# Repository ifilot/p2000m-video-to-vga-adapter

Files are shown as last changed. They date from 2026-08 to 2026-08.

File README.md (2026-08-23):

# Philips P2000M video to VGA adapter



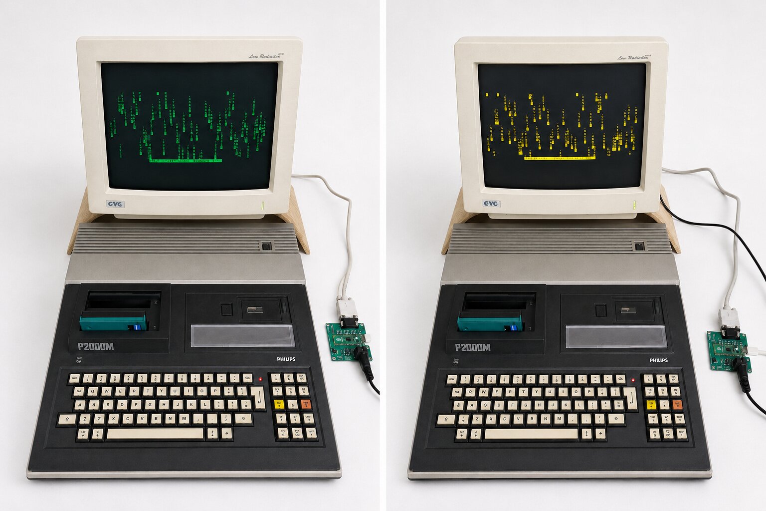
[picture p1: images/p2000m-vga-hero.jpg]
Philips P2000M connected to a monitor through the VID2VGA adapter


This repository contains the adapter PCB and Raspberry Pi Pico 2 firmware for
converting the Philips P2000M raw monochrome video output to VGA.

The adapter captures the conditioned P2000M signals on GPIO16-18,
recovers the source dot grid in software, and presents a tear-free 640 x 288
source image in a 640 x 480, 60 Hz VGA raster. The asynchronous 50.095 Hz
source is repeated as needed at VGA frame boundaries.

By default, the 288 source lines are displayed one-to-one between 96-line top
and bottom margins. An optional fit mode expands them to all 480 VGA lines using
symmetric nearest-neighbour 5:3 scaling. Each three-line source group becomes
five output lines in a 2,1,2 repetition pattern, preserving hard text edges
without introducing gray interpolation pixels.

## Hardware

The adapter conditions the P2000M video and synchronization signals for the
Pico 2, then converts the Pico's 12-bit RGB output and synchronization signals
to a standard VGA connection.

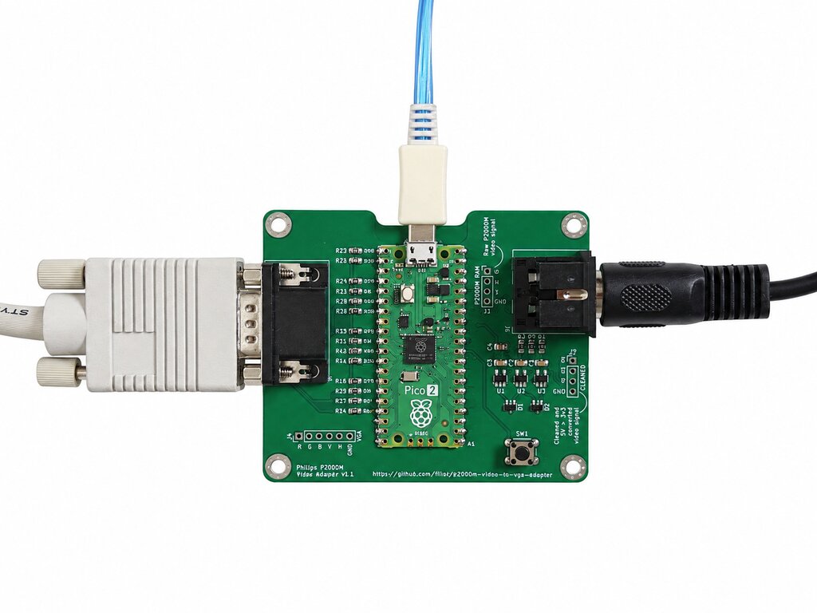
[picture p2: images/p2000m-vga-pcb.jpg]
Assembled P2000M VID2VGA adapter PCB with connected cables


*Assembled adapter PCB. The board design is in
[`pcb/p2000m-to-vga-adapter.kicad_pcb`](pcb/p2000m-to-vga-adapter.kicad_pcb).*

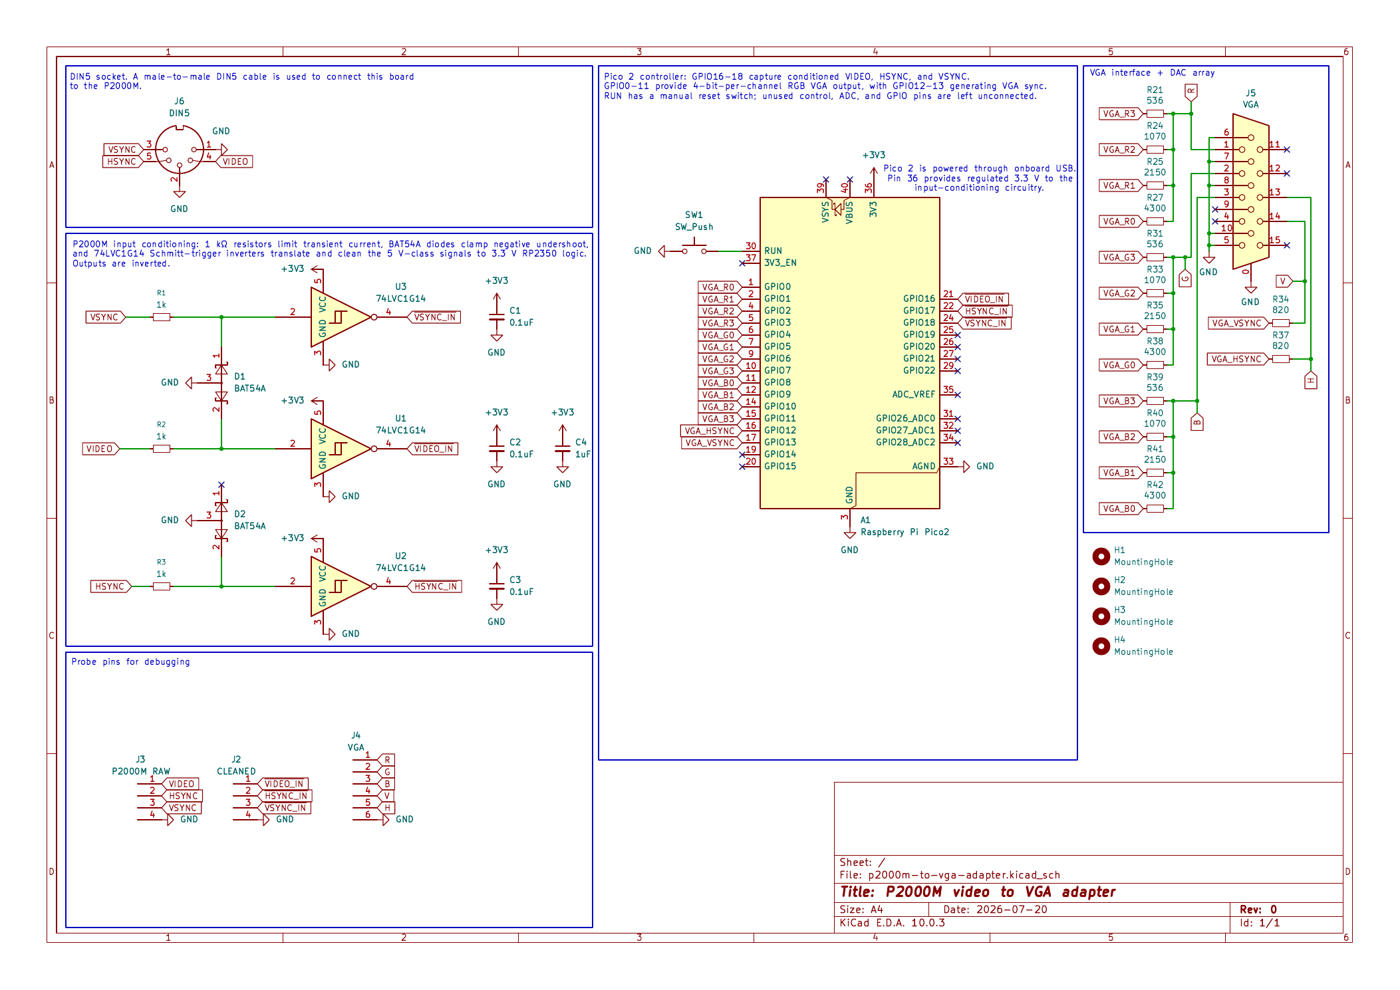
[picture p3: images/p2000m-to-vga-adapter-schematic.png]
Circuit schematic for the P2000M VID2VGA adapter


*Circuit schematic. Select the image to open the PDF; the editable source is
[`pcb/p2000m-to-vga-adapter.kicad_sch`](pcb/p2000m-to-vga-adapter.kicad_sch).*

### Enclosure

A two-part 3D-printable enclosure protects the assembled adapter while keeping
its connectors, USB port, and controls accessible. Ready-to-print models are
available as [`enclosure/v1/top.stl`](enclosure/v1/top.stl) and
[`enclosure/v1/bottom.stl`](enclosure/v1/bottom.stl).

<p align="center">
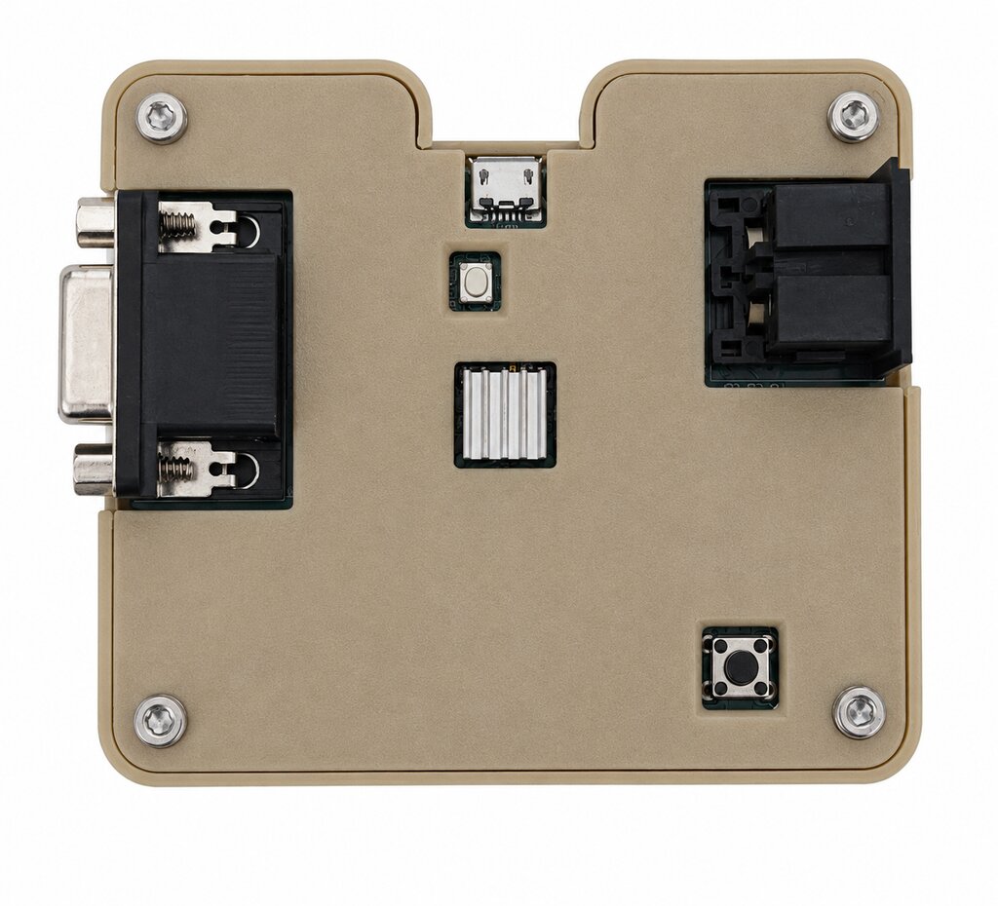
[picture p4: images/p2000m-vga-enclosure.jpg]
P2000M VID2VGA adapter fitted in its enclosure
  
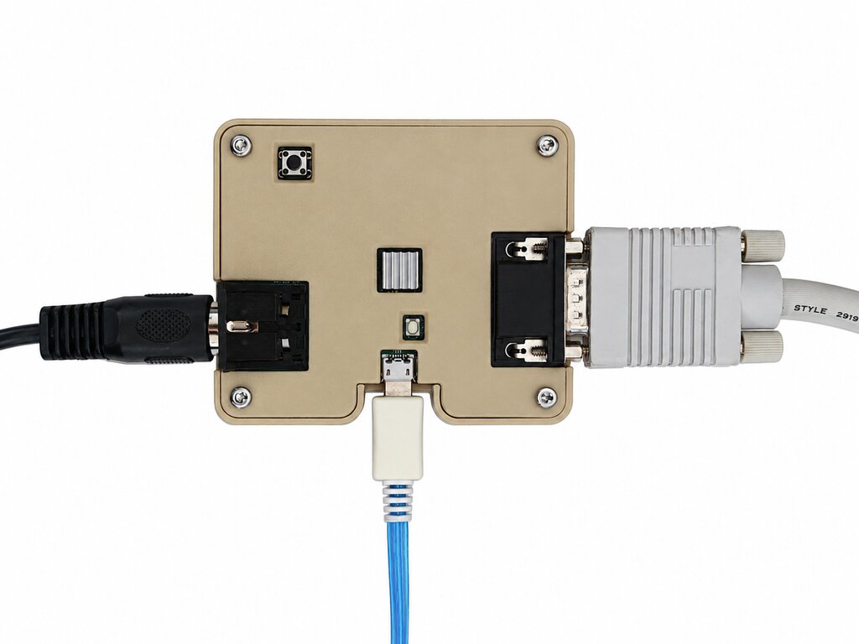
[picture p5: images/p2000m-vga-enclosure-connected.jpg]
Enclosed P2000M VID2VGA adapter with cables connected
  
</p>

## Building

The build requires Git, CMake, Ninja, and an Arm GNU embedded toolchain. The
first configuration automatically downloads the pinned Pico SDK 2.3.0 and
matching `pico-extras` release into the build directory; later configurations
reuse those checkouts.

On Debian or Ubuntu, install the host tools and cross-compiler with:

```sh
sudo apt update
sudo apt install git cmake ninja-build build-essential \
  gcc-arm-none-eabi libnewlib-arm-none-eabi \
  libstdc++-arm-none-eabi-newlib
```

```sh
cmake -S . -B build -G Ninja \
  -DCMAKE_BUILD_TYPE=Release
cmake --build build
```

Pico 2 and its `rp2350-arm-s` platform are project defaults, so
`-DPICO_BOARD=pico2` is no longer necessary.

For an offline or custom SDK installation, explicitly pass
`-DPICO_SDK_PATH=/path/to/pico-sdk` and
`-DPICO_EXTRAS_PATH=/path/to/pico-extras`; these overrides take precedence over
automatic downloading.

Flash the single generated image:

```text
build/src/p2000m-vid2vga-firmware.uf2
```

> [!WARNING]
> The current experimental firmware runs the RP2350 at 252 MHz and 1.30 V,
> beyond Raspberry Pi's 150 MHz rating. This preserves exact integer divisors
> for the 63 MHz capture and 25.2 MHz VGA clocks, but stability, temperature,
> lifetime, and operation across devices are not guaranteed. BOOTSEL recovery
> remains available if the firmware does not start reliably. The configuration
> that sustained 25 FPS was tested with a cooling block fitted directly to the
> RP2350 package. A properly mounted heatsink or equivalent cooling block, with
> adequate surrounding airflow, is strongly recommended for prolonged use at
> 252 MHz; cooling reduces thermal risk but does not make the overclock an
> in-spec operating condition.

### Desktop screen viewer

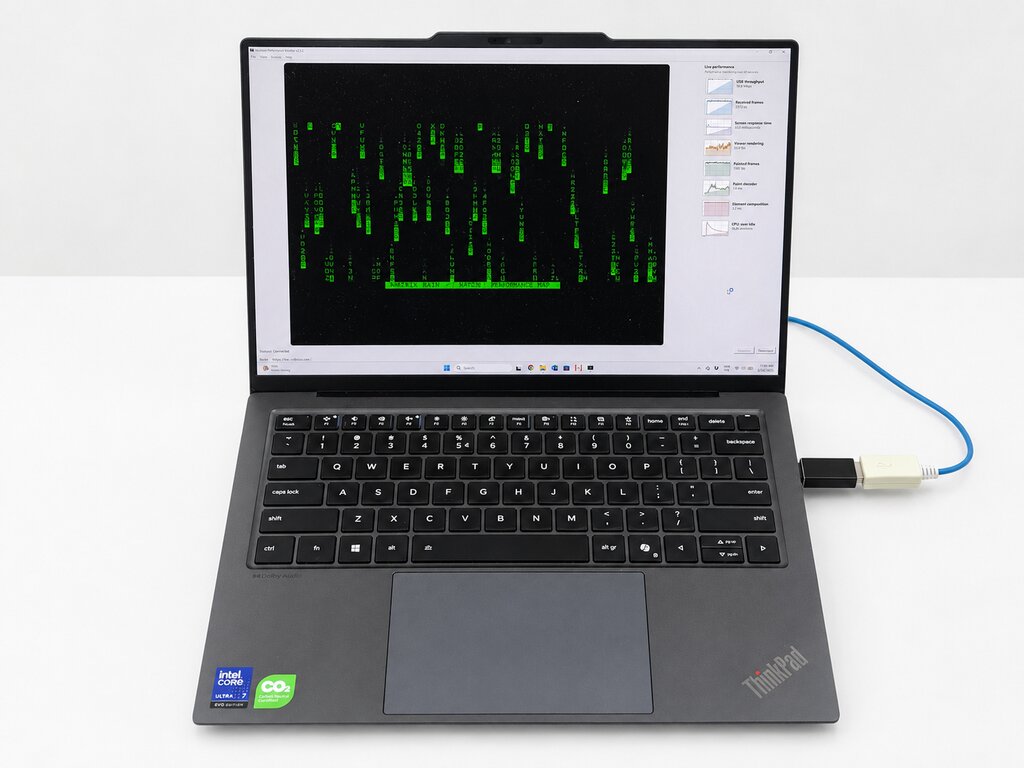
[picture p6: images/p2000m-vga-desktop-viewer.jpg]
P2000M desktop screen viewer running on a laptop


The `gui` directory contains a Qt 6 application for Windows, Linux, and macOS.
It automatically finds Raspberry Pi Pico CDC ports, verifies the VID2VGA
firmware, switches the adapter into binary screen mode, and displays complete
CRC-checked frames. It
returns the adapter to console mode when Disconnect is selected or the window
is closed. Its Adapter menu can configure colors, borders, scaling, phosphor
grain, sampling phase, and optional persistent storage through the firmware's
console.
The viewer uses a monitor-derived application icon, places rolling live
performance graphs beside the screen, and keeps the status bar focused on the
COM port and source frame number. It can save lossless screenshots and can
record H.264 MP4 video through the FFmpeg runtime included in every packaged
viewer distribution.

Build it from an MSYS2 UCRT64 shell with Qt 6 installed:

```sh
cmake -S gui -B build-gui -G Ninja -DCMAKE_BUILD_TYPE=Release
cmake --build build-gui
```

See [`gui/README.md`](gui/README.md) for use and build instructions and
[`gui/PACKAGING.md`](gui/PACKAGING.md) for CI packaging and tagged releases.

## Video capture and VGA conversion

The P2000M connector does not carry a VGA-compatible raster. It exposes a
one-bit monochrome `VIDEO` signal plus separate `HSYNC` and `VSYNC` timing
signals. The adapter first converts those signals to safe 3.3 V logic, then the
Pico measures and reconstructs the original dot grid before generating a new,
independent VGA raster. The complete path is:

```text
P2000M DIN-5 -> protection and Schmitt-trigger conditioning
             -> PIO sampling and DMA raw-frame buffers
             -> 640 x 288 one-bit reconstructed frames
             -> color mapping and 640 x 480 VGA scanout
```

### P2000M source timing

The P2000M derives its display timing from a 12 MHz dot clock. Eight dots form
one character time and 96 character times form one 64 microsecond scanline.
Only 80 character times contain picture data, giving 640 visible dots per line.
Twelve scanlines form a character row and 26 hardware rows form a frame, for a
nominal frame rate of approximately 50.1 Hz.

The 24 rows stored in video memory do not have the same numbers as the hardware
timing rows. Video-memory rows 0 through 23 appear in hardware rows 1 through
24. Hardware rows 25 and 0 are part of the vertical blanking and preparation
interval. `VSYNC` is active during hardware row 24, the final visible row:

```text
hardware row 24  video-memory row 23; VSYNC active
hardware row 25  vertical blanking                     } skipped
hardware row 0   vertical blanking / row preparation   } skipped
hardware row 1   video-memory row 0; capture starts
       ...
hardware row 24  video-memory row 23; capture ends
```

The capture state machine waits for the trailing edge of the active-low
conditioned `VSYNC`, which marks the start of hardware row 25. It then counts 24
`HSYNC` edges to skip hardware rows 25 and 0. Capturing the following 288
scanlines therefore covers hardware rows 1 through 24, or exactly 80 x 24
characters. This distinction is important: treating the assertion of `VSYNC`
as row 0 would capture one blank character row and omit video-memory row 23.

### Probing and input conditioning

The three P2000M signals enter through the DIN-5 connector. Each input has a
1 kΩ series resistor to limit transient current and a BAT54A clamp for negative
undershoot. A 3.3 V-powered 74LVC1G14 Schmitt-trigger inverter translates the
5 V-class input to RP2350 logic levels, cleans up slow or noisy edges, and
inverts its polarity before it reaches the Pico:

| P2000M signal | Conditioned signal | Pico input | Purpose |
| --- | --- | --- | --- |
| `VIDEO` | `~VIDEO_IN` | GPIO16 | Monochrome dot level |
| `HSYNC` | `~HSYNC_IN` | GPIO17 | Start reference for every scanline |
| `VSYNC` | `~VSYNC_IN` | GPIO18 | Frame and hardware-row reference |

All three conditioned inputs are consequently active-low. For `VIDEO`, a low
sample represents foreground and a high sample represents background.

### Line capture and pixel reconstruction

PIO1 runs at 63 MHz and anchors every captured line independently to the
leading edge of conditioned `HSYNC`. After a fixed delay to just before the
active picture, it oversamples `VIDEO` for 54.286 microseconds. Independent
line synchronization prevents small timing errors from accumulating vertically.

The PIO loop takes 14 consecutive samples followed by one branch cycle without
a sample. Two loops are packed into each DMA word, so a word holds 28 useful
samples representing 30 PIO clock ticks. A line contains 114 words and a raw
frame contains 288 such lines. DMA writes complete frames into three buffers so
capture can continue while software reads an older completed frame.

The source clock is not phase-locked to the Pico. The firmware therefore
measures the source frame period, divides it over the known 312 scanlines and
768 dot periods per line, and builds a map from each of the 640 output pixels to
the appropriate raw samples. It tests five nearby horizontal phases and selects
the phase with the strongest foreground content. For each reconstructed pixel,
three adjacent samples are examined; if any is foreground, the output pixel is
foreground. This preserves narrow character strokes without introducing gray
interpolation pixels. A double-buffered map ensures that a timing adjustment
cannot change partway through decoding a frame.

Core 0 converts the newest completed raw capture into a packed 640 x 288 one-bit
frame. Three decoded-frame buffers separate this work from VGA generation on
core 1.

### VGA presentation

The Pico generates a standard 640 x 480 raster with a 25.2 MHz pixel clock and
a nominal 60 Hz refresh rate. The P2000M and VGA rates are asynchronous, so core
1 switches to the newest decoded source frame only at the beginning of a VGA
frame. If no newer P2000M frame is ready, it repeats the current one. A VGA
frame can therefore never contain parts of two source frames.

Complete captured frames also act as a synchronization watchdog. If valid
HSYNC/VSYNC-driven frames stop arriving for 100 ms, VGA remains active and
shows a centered `SIGNAL LOST` warning instead of indefinitely freezing the
last source image. The status card also identifies the adapter and its compiled
firmware version and indicates that capture is waiting for both synchronization
inputs. Live video returns only after two consecutive frame completions
establish a credible source period, preventing a partial recovery frame from
reaching the display.

Horizontally, all 640 reconstructed source pixels map directly to the 640 VGA
pixels. Vertically, native mode presents all 288 source lines one-to-one between
96-line top and bottom margins. Fit mode expands them to 480 lines with
symmetric nearest-neighbour 5:3 scaling: each three-line source group becomes a
2,1,2 pattern of repeated VGA lines.

The one-bit image selects the configured foreground or background color. The
optional border is added during scanout, so it can use an independent color and
a solid or dotted pattern without expanding the one-bit frame buffers. Optional
phosphor grain uses a source-frame-synchronous pseudorandom mask to dim only
foreground pixels by one RGB444 DAC step. Low, medium, and high select roughly
one eighth, one quarter, or one half of the lit pixels; background, borders,
and the captured framebuffer remain unchanged. GPIO0 through GPIO11 carry four
bits each of red, green, and blue through the resistor DAC, while GPIO12 and
GPIO13 generate VGA synchronization. After every 640-pixel picture line, the
scanout emits black before horizontal blanking so the analog RGB outputs return
to a defined level before synchronization.

## USB controls

Connect a terminal to the Pico USB CDC serial port. Commands are
case-insensitive and execute when Enter is pressed. Command mode echoes input,
supports Backspace/Delete, displays a `vid2vga>` prompt, and produces no
unsolicited statistics.

- `status` or `s`: print capture, decoder, resampler, and VGA statistics.
- `version` or `v`: print the semantic firmware version.
- `license`: print the firmware copyright, license, warranty, and source
  location.
- `log`: stream those statistics every two seconds. Press Enter, Escape, or
  `q` to stop the stream and return to the command prompt.
- `screen [raw|packbits]`: enter the continuous binary framebuffer interface
  used by the Windows viewer. TinyUSB backpressure safely pauses transmission
  when the host cannot keep up, `console` returns to the normal terminal
  interface, and the legacy `frame` command remains accepted for viewer
  compatibility. Omitting the encoding selects raw records.
- `settings`: print all active settings and whether they are factory defaults,
  modified in RAM, or saved in flash.
- `border on`, `border off`, or `border toggle`: control a one-pixel rectangle
  around the 640 x 288 source image.
- `border-color <color>`: set the border color independently of the foreground
  and background colors.
- `border-style solid` or `border-style dotted`: select a continuous border or
  a two-pixel-on, two-pixel-off pattern whose gaps reveal the source image.
- `scale fit`: expand 288 source lines to the full 480-line VGA height.
- `scale native`: show the original 288 lines between 96-line margins.
- `noise off`, `noise low`, `noise medium`, or `noise high`: select the density
  of one-DAC-step phosphor grain applied to foreground pixels.
- `fg <color>`: set the foreground/text color.
- `bg <color>`: set the background color, including the top and bottom margins.
- `colors`: list the named presets.
- `defaults`: restore white on black, a disabled solid magenta (`#FF00FF`)
  border, native 1:1 scaling, and disabled phosphor grain.
- `save`: explicitly save the current colors, border state, border pattern,
  scaling mode, phosphor-grain level, and manual phase trim. These settings are
  restored after reset or power cycling.
- `factory-reset`: erase the saved configuration and immediately restore the
  factory display style and zero manual phase trim.
- `tune` or `j`: run automatic phase tuning and print all candidate scores.
- `phase +`, `phase -`, or `phase auto`: adjust or clear the manual phase trim.
- `geometry` or `g`: print coverage totals for all 80 x 24 character cells.
- `help`, `h`, or `?`: print the command reference.

Colors may be selected by name (`black`, `white`, `green`, `amber`, `cyan`,
`magenta`, `red`, `blue`, `yellow`, or `gray`) or entered as `RRGGBB`,
`#RRGGBB`, or `0xRRGGBB`. The VGA output hardware is RGB444, so the upper four
bits of each entered eight-bit channel determine the physical output level.

Settings are only written when `save` is entered, avoiding unnecessary flash
wear while experimenting. Two versioned, checksummed flash records are used in
alternation, so an interrupted save leaves the previous valid configuration
available. Saving or erasing briefly pauses both cores and may cause a momentary
VGA blink. Automatic phase selection is always recalculated from the live
signal; only the user's manual phase trim is persistent.

Automatic tuning runs about once every five seconds. The `stale_replaced`
counter normally increases when newer raw frames supersede frames that no
consumer needed; it is not itself a capture failure.

Screen mode sends a 48-byte versioned header followed by a complete packed
monochrome framebuffer. Type-one records contain the native 23,040-byte image.
Type-two records use standard PackBits controls: 0 through 127 introduce 1
through 128 literal bytes, 129 through 255 repeat the next byte 128 through 2
times, and 128 is a no-op. PackBits is selected independently for each frame
only when smaller than raw data, so incompressible screens cannot expand the
USB traffic. PackBits runs are aggregated into approximately 1 KiB staging
blocks before entering TinyUSB. The payload-size header field describes the
transmitted data and its CRC-32 always covers the reconstructed 23,040-byte
framebuffer. When flags bit 2 is set, header bytes 12 through 15 contain two
little-endian 16-bit diagnostics: current preparation time and previous-frame
streaming-encoder CPU time, both in microseconds.
Header style bits 3 and 4 carry the phosphor-grain level; the packed payload and
its checksum continue to describe the pristine one-bit source framebuffer.

Frames are independently recoverable and limited to every second decoded
source sequence (approximately 25.05 frames per second).
USB transmission is continuous and best effort: a slow or disconnected host
can reduce the viewer rate but cannot take the framebuffer currently required
by VGA output. The current viewer selects raw records by default and offers
PackBits as an experimental Adapter-menu option. It also negotiates the older
per-frame credit mode when connected to an earlier compatible firmware build.
Plain `screen` remains raw for older viewer compatibility.

## Licensing

This is a multi-license project:

- The firmware, build configuration, CI workflow, and P2000M screen-test
  program are licensed under the
  [GNU GPL version 3 or later](LICENSES/GPL-3.0-or-later.txt).
- The PCB, schematic, custom footprints, and generated hardware views are
  licensed under the
  [CERN Open Hardware Licence Version 2—Strongly Reciprocal](LICENSES/CERN-OHL-S-2.0.txt).
- This README and the changelog are licensed under
  [Creative Commons Attribution 4.0](LICENSES/CC-BY-4.0.txt).

See [LICENSE.md](LICENSE.md) for the exact file scopes and
[THIRD_PARTY_NOTICES.md](THIRD_PARTY_NOTICES.md) for components incorporated
from the Raspberry Pi Pico SDK, `pico-extras`, and TinyUSB.

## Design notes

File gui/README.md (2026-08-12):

<!--
SPDX-FileCopyrightText: 2026 Ivo Filot <ivo@ivofilot.nl>
SPDX-License-Identifier: CC-BY-4.0
-->

# P2000M VID2VGA Viewer

The Qt 6 viewer automatically enumerates Raspberry Pi Pico USB CDC ports on
Windows, Linux, and macOS, verifies the VID2VGA firmware, enters binary screen
mode, and displays complete CRC-checked frames. Disconnecting or closing the
application returns the adapter to its normal console mode. The application
version is visible in the window title, **Help > About**, Qt application metadata, and the Windows
executable properties.

The viewer uses continuous streaming with current firmware to avoid a USB
command round trip between frames. It automatically falls back to per-frame
credits when it recognizes an earlier version-one firmware announcement. Raw
streaming is the default. **Adapter > Stream Encoding** can switch a live
connection to experimental PackBits mode without reconnecting; compressed
records have their expanded CRC-32 validated and fall back to raw whenever
compression is ineffective.

The right-hand **Live performance** panel plots approximately 60 seconds of
rolling history for USB throughput, received and painted frame rates, source
sequence step, payload size, rendering and PackBits times, paint time,
firmware preparation and encoding times, and the rolling CRC-error rate. Raw
mode hides the payload-size, PackBits-unpacking, and firmware-encoding graphs
because those compression metrics do not apply. The status bar is reserved
for operational information: the active COM port, source frame number,
cumulative CRC errors for the current capture, and recording state.

The **Adapter > Configure Adapter** dialog controls foreground, background,
border color and style, vertical scaling, foreground phosphor grain, and
sampling-phase trim. **Apply** changes the running configuration; **Apply &
Save** also stores it in the adapter's redundant flash settings slots. The
viewer briefly pauses screen traffic, uses the firmware's normal USB console
commands, and resumes the binary stream on the same COM port. Grain controls
are disabled when connected to firmware older than v0.4.0. The foreground can
be selected from Matrix green, retro amber, and warm off-white presets or from
the unrestricted custom color picker.

The menu bar also provides connection controls, lossless framebuffer
screenshots, and MP4 recordings under **File**, plus application and license
information under **Help > About**. Both save dialogs offer a remembered option
to add a 12 px black border, producing a 664 x 504 image instead of the native
640 x 480 frame. Recordings are encoded by a separate FFmpeg process, keeping
video compression away from the serial and painting paths. The live monitor
viewport has a permanent 12 px black bezel with rounded outer and screen
corners; this presentation-only surround is not included in captures. If the
adapter remains connected but valid source frames stop for 100 ms, the viewer
shows the same `SIGNAL LOST` card as the VGA output and restores the live image
as soon as capture resumes. **View > Scaling
Filter** switches between smooth anti-aliased resizing and sharp
nearest-neighbor pixels. Pixel-perfect integer scaling avoids uneven pixel
widths. **View > CRT Phosphor Afterglow** optionally retains decaying light
from earlier frames; its brightness half-life is tunable from 10 to 1000 ms
and both settings persist between viewer sessions. The effect is limited to
presentation, so recordings and lossless framebuffer screenshots retain the
unfiltered adapter image. **F11** enters a clean full-screen presentation and
**Escape** leaves it. The monitor-derived application icon is used by the
executable, main window, dialogs, and taskbar.

The application uses SetupAPI and direct COM access on Windows, preserving the
high-throughput path tested with the adapter. Linux and macOS use a compact
native POSIX serial backend. Qt Serial Port is therefore not required on any
platform; the only Qt dependency is Qt 6 Base.

Build from an MSYS2 UCRT64 shell:

```sh
pacman -S --needed mingw-w64-ucrt-x86_64-qt6-base
cmake -S gui -B build-gui -G Ninja -DCMAKE_BUILD_TYPE=Release
cmake --build build-gui
```

Every distributed viewer package includes a private, smoke-tested FFmpeg/x264
runtime for H.264 recording. The viewer selects that copy before considering a
developer installation on `PATH`. Exact corresponding source archives,
license texts, checksums, and configure arguments are included under
`licenses/ffmpeg`; no separate FFmpeg installation is required.

See [PACKAGING.md](PACKAGING.md) for Linux and macOS builds, package formats,
the default-branch package checks, and the exact-commit tag release process.

The following creates a development directory containing the executable and
its Qt runtime DLLs. It is not a distributable package until the pinned FFmpeg
runtime has also been built and bundled as described in [PACKAGING.md](PACKAGING.md):

```sh
mkdir -p build-gui/package
cp build-gui/p2000m-vid2vga-viewer.exe build-gui/package/
windeployqt6 --release --no-translations \
  build-gui/package/p2000m-vid2vga-viewer.exe
```

MSYS2's Qt packages use several shared UCRT64 libraries which
`windeployqt6` does not copy. Add their recursively discovered dependencies
when the package must run without an MSYS2 `PATH`:

```sh
for binary in $(find build-gui/package -type f \
    \( -name '*.exe' -o -name '*.dll' \)); do
  ldd "$binary"
done | awk '$3 ~ /^\/ucrt64\/bin\// { print $3 }' | sort -u | \
  xargs -r -I{} cp "{}" build-gui/package/
```

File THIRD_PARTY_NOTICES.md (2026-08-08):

<!--
SPDX-FileCopyrightText: 2026 Ivo Filot <ivo@ivofilot.nl>
SPDX-FileCopyrightText: 2020 Raspberry Pi (Trading) Ltd.
SPDX-FileCopyrightText: 2018 hathach (tinyusb.org)
SPDX-License-Identifier: CC-BY-4.0 AND BSD-3-Clause AND MIT
-->

# Third-party notices

The firmware build downloads the pinned Raspberry Pi Pico SDK 2.3.0 and the
matching `pico-extras` release. The generated firmware incorporates portions of
those projects and TinyUSB. Those portions retain their original licenses and
copyright notices. The project's GPL license does not replace them.

The exact dependency source is available from:

- <https://github.com/raspberrypi/pico-sdk/tree/2.3.0>
- <https://github.com/raspberrypi/pico-extras/tree/sdk-2.3.0>
- <https://github.com/hathach/tinyusb/tree/86ad6e56c1700e85f1c5678607a762cfe3aa2f47>

Release packages of the optional desktop viewer also contain dynamically
linked Qt 6 runtime libraries and plugins. Those unmodified libraries retain
their Qt Project licensing, including the GNU Lesser General Public License
version 3 where applicable. Viewer packaging copies the license files supplied
with the exact Qt distribution into the package. Qt source releases and the
corresponding license information are available from <https://www.qt.io/>.

Viewer packages include a private FFmpeg 8.1.2 executable built from unmodified
FFmpeg source and statically linked with x264 revision
`b35605ace3ddf7c1a5d67a2eb553f034aef41d55`. The executable is a separate
process connected to the viewer through standard input. FFmpeg is configured
with `--enable-gpl --enable-version3 --enable-libx264`, so the resulting
runtime is distributed under GNU GPL version 3 or later. x264 is distributed
under GNU GPL version 2 or later.

Every viewer package contains the complete, exact FFmpeg and x264 source
archives used for that platform build, their license texts, SHA-256 checksums,
the full configure arguments, and the runtime's own version report under
`licenses/ffmpeg`. The authoritative upstream locations are:

- <https://ffmpeg.org/releases/ffmpeg-8.1.2.tar.xz>
- <https://code.videolan.org/videolan/x264/-/commit/b35605ace3ddf7c1a5d67a2eb553f034aef41d55>

FFmpeg copyright © 2000–2026 the FFmpeg developers. x264 copyright © 2003–2025
the x264 project. No endorsement by either project is implied.

## Raspberry Pi Pico SDK and pico-extras

Copyright 2020 (c) 2020 Raspberry Pi (Trading) Ltd.

Redistribution and use in source and binary forms, with or without
modification, are permitted provided that the following conditions are met:

1. Redistributions of source code must retain the above copyright notice,
   this list of conditions and the following disclaimer.
2. Redistributions in binary form must reproduce the above copyright notice,
   this list of conditions and the following disclaimer in the documentation
   and/or other materials provided with the distribution.
3. Neither the name of the copyright holder nor the names of its contributors
   may be used to endorse or promote products derived from this software
   without specific prior written permission.

THIS SOFTWARE IS PROVIDED BY THE COPYRIGHT HOLDERS AND CONTRIBUTORS "AS IS"
AND ANY EXPRESS OR IMPLIED WARRANTIES, INCLUDING, BUT NOT LIMITED TO, THE
IMPLIED WARRANTIES OF MERCHANTABILITY AND FITNESS FOR A PARTICULAR PURPOSE ARE
DISCLAIMED. IN NO EVENT SHALL THE COPYRIGHT HOLDER OR CONTRIBUTORS BE LIABLE
FOR ANY DIRECT, INDIRECT, INCIDENTAL, SPECIAL, EXEMPLARY, OR CONSEQUENTIAL
DAMAGES (INCLUDING, BUT NOT LIMITED TO, PROCUREMENT OF SUBSTITUTE GOODS OR
SERVICES; LOSS OF USE, DATA, OR PROFITS; OR BUSINESS INTERRUPTION) HOWEVER
CAUSED AND ON ANY THEORY OF LIABILITY, WHETHER IN CONTRACT, STRICT LIABILITY,
OR TORT (INCLUDING NEGLIGENCE OR OTHERWISE) ARISING IN ANY WAY OUT OF THE USE
OF THIS SOFTWARE, EVEN IF ADVISED OF THE POSSIBILITY OF SUCH DAMAGE.

License: `BSD-3-Clause`

## TinyUSB

Copyright (c) 2018, hathach (tinyusb.org)

Permission is hereby granted, free of charge, to any person obtaining a copy of
this software and associated documentation files (the "Software"), to deal in
the Software without restriction, including without limitation the rights to
use, copy, modify, merge, publish, distribute, sublicense, and/or sell copies of
the Software, and to permit persons to whom the Software is furnished to do so,
subject to the following conditions:

The above copyright notice and this permission notice shall be included in all
copies or substantial portions of the Software.

THE SOFTWARE IS PROVIDED "AS IS", WITHOUT WARRANTY OF ANY KIND, EXPRESS OR
IMPLIED, INCLUDING BUT NOT LIMITED TO THE WARRANTIES OF MERCHANTABILITY,
FITNESS FOR A PARTICULAR PURPOSE AND NONINFRINGEMENT. IN NO EVENT SHALL THE
AUTHORS OR COPYRIGHT HOLDERS BE LIABLE FOR ANY CLAIM, DAMAGES OR OTHER
LIABILITY, WHETHER IN AN ACTION OF CONTRACT, TORT OR OTHERWISE, ARISING FROM,
OUT OF OR IN CONNECTION WITH THE SOFTWARE OR THE USE OR OTHER DEALINGS IN THE
SOFTWARE.

License: `MIT`

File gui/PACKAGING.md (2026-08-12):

<!--
SPDX-FileCopyrightText: 2026 Ivo Filot <ivo@ivofilot.nl>
SPDX-License-Identifier: CC-BY-4.0
-->

# Desktop viewer packaging and releases

The viewer is released in four packages:

| Platform | Architecture | Package |
| --- | --- | --- |
| Windows | x86-64 | Graphical offline installer and portable ZIP |
| Linux | x86-64 | AppImage |
| macOS | Intel x86-64 | DMG |
| macOS | Apple silicon arm64 | DMG |

All packages contain a private FFmpeg 8.1.2 runtime with x264 H.264 support.
CI builds it from pinned authoritative source, validates both archives by
SHA-256, and performs a real MP4 encoding smoke test. Packages also contain the
exact FFmpeg and x264 source archives, license texts, checksums, configure
arguments, and runtime version report under `licenses/ffmpeg`.

The Windows installer is produced with NSIS. It installs the complete
application under Program Files, creates Start-menu and desktop shortcuts, and
provides a conventional Windows uninstaller. Its stable application identity
allows newer releases to upgrade the existing directory in place. The first
such upgrade also removes the broken Qt Installer Framework 0.3.0/0.3.1
maintenance metadata and registration. The ZIP remains available for users who
specifically need a no-install portable copy.

## Continuous package validation

`.github/workflows/gui-packages.yml` builds, tests, installs, deploys, and
packages all four targets on every push to `master`, on pull requests, and on
manual dispatch. A default-branch push retains its packages for 30 days under
artifact names containing the exact commit SHA.

`.github/workflows/firmware.yml` independently builds the Pico firmware on
every push and pull request. Default-branch pushes retain the tested UF2 and
license files using the same exact-commit convention.

Protecting `master` with the firmware check and all four GUI matrix checks is
recommended. This catches platform-specific compilation and deployment
failures before merge, rather than waiting for a release tag.

## Tagging and release promotion

`.github/workflows/release.yml` is intentionally a promotion workflow, not a
build workflow. For a tag such as `v0.3.2`, it:

1. verifies that the tag matches both CMake project versions and `CHANGELOG.md`;
2. finds successful firmware and GUI default-branch runs for the exact tagged
   commit;
3. downloads the artifacts produced by those runs;
4. verifies every expected package, including both Windows formats; and
5. creates or updates one GitHub release containing firmware and all desktop
   packages.

The release is refused if the commit was not tested successfully on `master`,
if an artifact has expired, or if any version or package is inconsistent.
Consequently, tagging cannot silently publish a partial or newly rebuilt set
of binaries.

Release procedure:

```sh
git switch master
git pull --ff-only

# Confirm Firmware and all four GUI package jobs are green for HEAD.
git tag -a v0.3.2 -m "Release v0.3.2"
git push origin v0.3.2
```

If artifacts have expired, rerun the original successful `master` workflows
for that commit before retrying the tag workflow. Do not recreate a release by
building packages locally: the release workflow accepts CI artifacts only.

## Local Windows package

The release workflow uses Qt 6.8.3 with MSVC 2022. Local MSYS2 UCRT64 builds
remain supported:

```sh
pacman -S --needed \
  base-devel \
  mingw-w64-ucrt-x86_64-cmake \
  mingw-w64-ucrt-x86_64-gcc \
  mingw-w64-ucrt-x86_64-nasm \
  mingw-w64-ucrt-x86_64-ninja \
  mingw-w64-ucrt-x86_64-pkgconf \
  mingw-w64-ucrt-x86_64-qt6-base

sh gui/packaging/build_ffmpeg.sh \
  "$PWD/ffmpeg-runtime" "$PWD/ffmpeg-work"
cmake -S gui -B build-gui -G Ninja -DCMAKE_BUILD_TYPE=Release
cmake --build build-gui
ctest --test-dir build-gui --output-on-failure
cmake --install build-gui --prefix stage
sh gui/packaging/bundle_ffmpeg.sh \
  "$PWD/ffmpeg-runtime" "$PWD/stage" windows
windeployqt6 --release --compiler-runtime --no-translations \
  stage/p2000m-vid2vga-viewer.exe
```

Archive the contents of `stage`, not the directory itself. To build the
graphical installer, install NSIS 3, ensure `makensis.exe` is on `PATH`, and
run:

```powershell
gui/packaging/create_windows_installer.ps1 `
  -Stage stage -Version 0.3.2 `
  -Output dist/p2000m-vid2vga-viewer-0.3.2-windows-x86_64-setup.exe `
  -WorkDirectory installer-work
```

The native Windows backend continues to use SetupAPI for Pico VID filtering
and direct COM I/O.

The Windows installer is currently unsigned because no Authenticode
certificate is configured for the repository. Windows SmartScreen may
therefore request confirmation on first launch. Signing should be added when
a code-signing certificate can be stored through protected GitHub Actions
secrets.

## Local Linux package

The normal build requires Qt 6.4 or newer. Install a C compiler, Make, curl,
pkg-config, and NASM before creating the bundled recording runtime:

```sh
sh gui/packaging/build_ffmpeg.sh \
  "$PWD/ffmpeg-runtime" "$PWD/ffmpeg-work"
cmake -S gui -B build-gui -G Ninja -DCMAKE_BUILD_TYPE=Release
cmake --build build-gui
ctest --test-dir build-gui --output-on-failure
cmake --install build-gui --prefix AppDir/usr
sh gui/packaging/bundle_ffmpeg.sh \
  "$PWD/ffmpeg-runtime" "$PWD/AppDir" linux
```

The CI workflow then runs pinned `linuxdeploy` and Qt-plugin releases to create
the AppImage. Follow the commands in `gui-packages.yml` when reproducing the
exact release package locally. Linux discovers Pico CDC devices as
`/dev/ttyACM*`. The user must have read/write access, normally through the
distribution's serial-device group or an appropriate udev rule.

A typical Debian-family rule is:

```udev
SUBSYSTEM=="tty", ATTRS{idVendor}=="2e8a", MODE="0660", GROUP="dialout", TAG+="uaccess"
```

Install it under `/etc/udev/rules.d/` using the administrator procedure for
the target distribution. Group names differ on some distributions, notably
those using `uucp` instead of `dialout`.

## Local macOS package

Install Qt 6, Ninja, Make, curl, pkg-config, and NASM, then build FFmpeg and
generate the required bundle icon before CMake configuration:

```sh
sh gui/packaging/build_ffmpeg.sh \
  "$PWD/ffmpeg-runtime" "$PWD/ffmpeg-work"
sh gui/packaging/create_macos_icon.sh \
  gui/assets/p2000m-vid2vga-viewer-icon.png \
  build-assets/p2000m-vid2vga-viewer.icns

cmake -S gui -B build-gui -G Ninja \
  -DCMAKE_BUILD_TYPE=Release \
  -DCMAKE_OSX_DEPLOYMENT_TARGET=12.0 \
  -DP2000M_MACOS_ICON="$PWD/build-assets/p2000m-vid2vga-viewer.icns"
cmake --build build-gui
ctest --test-dir build-gui --output-on-failure
cmake --install build-gui --prefix stage
sh gui/packaging/bundle_ffmpeg.sh \
  "$PWD/ffmpeg-runtime" "$PWD/stage" macos
macdeployqt "stage/P2000M VID2VGA Viewer.app" -always-overwrite \
  -executable="stage/P2000M VID2VGA Viewer.app/Contents/Resources/tools/ffmpeg" \
  -dmg
```

macOS discovers Pico devices as `/dev/cu.usbmodem*`. The CI packages are
architecture-specific rather than universal, avoiding a falsely universal
bundle containing single-architecture Qt libraries.

The current DMGs are unsigned and not notarized because the repository has no
Apple Developer ID credentials. Gatekeeper may therefore require users to
approve the first launch explicitly. Signing and notarization should be added
only when a Developer ID certificate and App Store Connect credentials can be
stored as protected GitHub Actions secrets.

## Deployment and licensing details

- Windows uses `windeployqt`; macOS uses `macdeployqt`; Linux uses the actively
  maintained `linuxdeploy` project and its Qt plugin.
- Packages contain shared Qt libraries and the Qt license files supplied by
  the selected Qt distribution.
- Project license and third-party notice files are installed in every package.
- FFmpeg and x264 are built from the versions and hashes in `ffmpeg.env`.
  Updating either dependency requires updating its version/revision, archive
  URL, SHA-256, notices, and the bundled source archive as one reviewed change.
- The Windows installer presents the viewer's GPL agreement before
  installation. All formats place the complete third-party license set and
  exact corresponding sources beside the installed application.
- The release workflow publishes exactly the assets tested on `master`; it
  never substitutes binaries produced by the tag event.

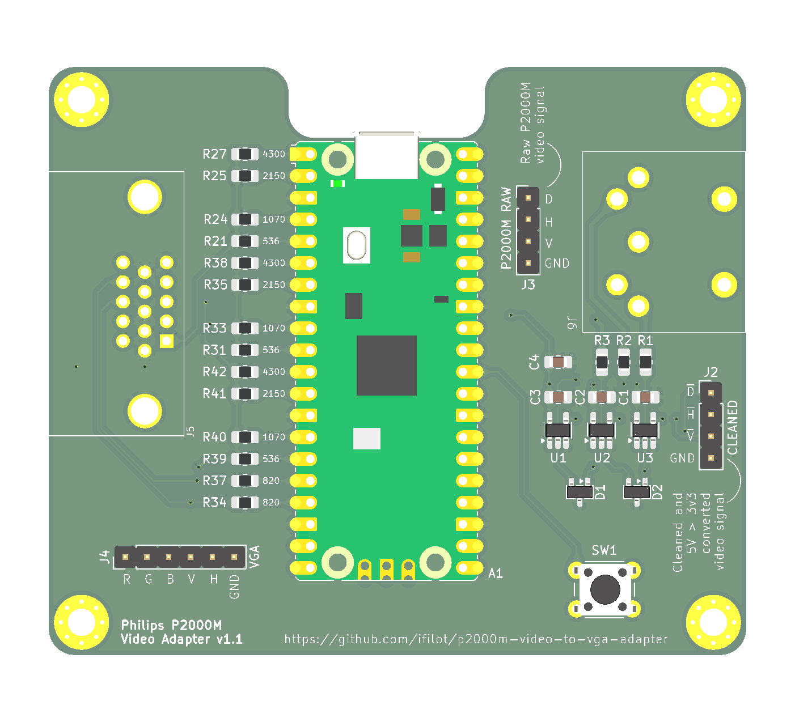
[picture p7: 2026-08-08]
images/p2000m-to-vga-adapter.png

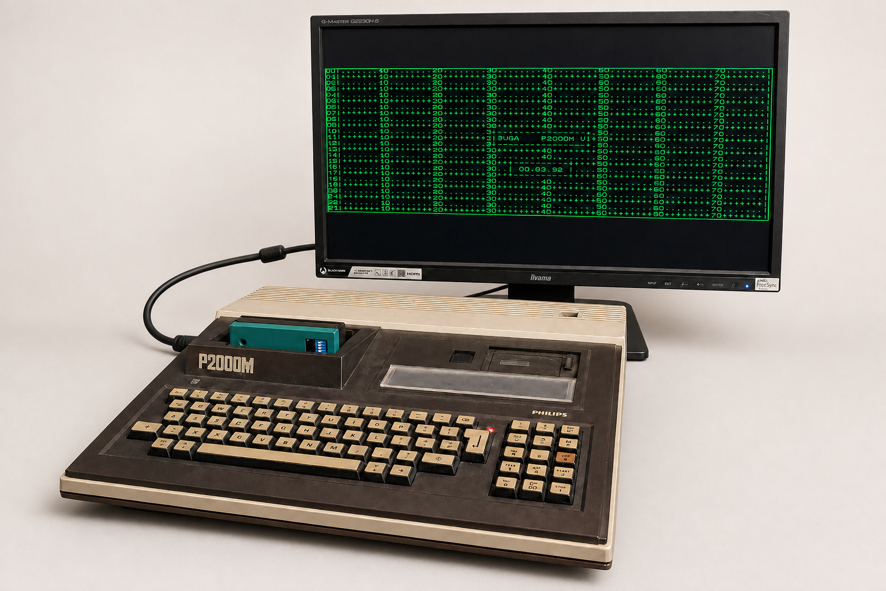
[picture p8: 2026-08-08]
images/p2000m-vga-hero.png

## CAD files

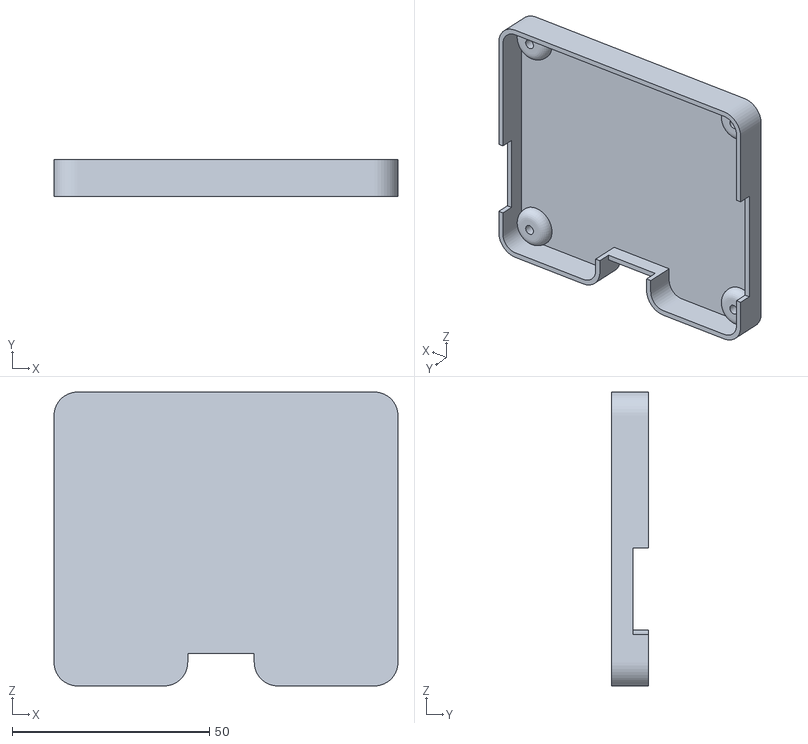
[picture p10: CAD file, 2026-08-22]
enclosure/v1/bottom.stl
87.3 x 9.51 x 74.6

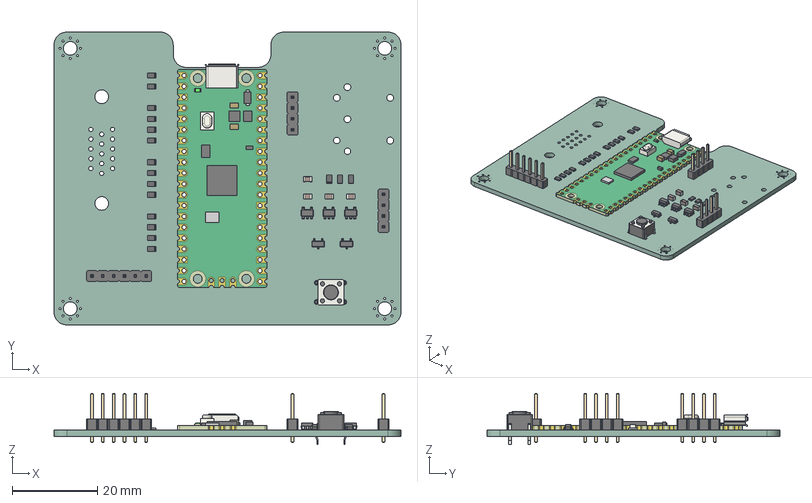
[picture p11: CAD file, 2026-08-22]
pcb/p2000m-vga-v1.step
81.3 x 68.6 x 12.0 mm
R_0805_2012Metric x 17
SOT-23 x 2
PinHeader_1x04_P254mm_Vertical x 2
PinHeader_1x06_P254mm_Vertical
C_0805_2012Metric x 4
SOT-23-5 x 3
SW_PUSH_6mm
RaspberryPi_Pico_Module_KiCad
p2000m-to-vga-adapter_PCB

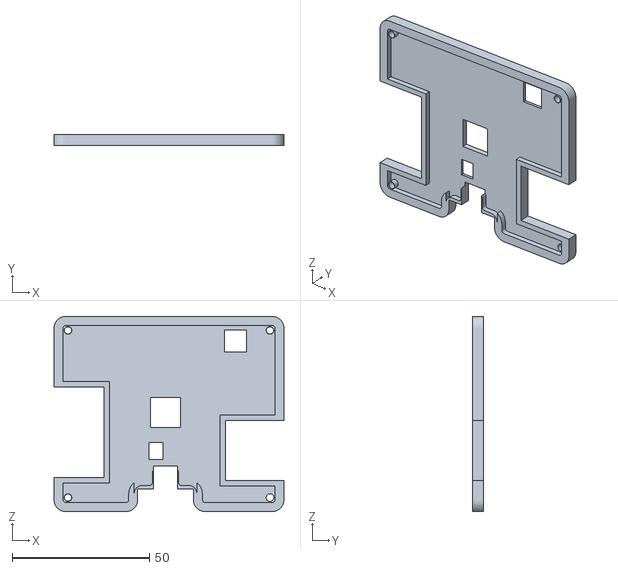
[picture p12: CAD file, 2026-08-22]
enclosure/v1/top.stl
83.9 x 4.00 x 71.2

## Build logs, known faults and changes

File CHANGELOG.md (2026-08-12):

<!--
SPDX-FileCopyrightText: 2026 Ivo Filot <ivo@ivofilot.nl>
SPDX-License-Identifier: CC-BY-4.0
-->

# Changelog

All notable changes to the P2000M VID2VGA firmware are documented here. The
format is based on [Keep a Changelog](https://keepachangelog.com/en/1.1.0/),
and releases use [Semantic Versioning](https://semver.org/).

## [0.4.0] - 2026-08-12

### Added

- Optional `low`, `medium`, and `high` phosphor-grain levels which dim a
  source-frame-synchronous random selection of foreground pixels by one RGB444
  DAC step without modifying the captured one-bit framebuffer.
- Persistent phosphor-grain configuration through the USB console and the
  viewer's adapter dialog, with automatic migration of older saved settings.
- Viewer reproduction of the firmware grain pattern using spare screen-record
  style bits, while retaining compatibility with earlier firmware.
- Viewer foreground presets for Matrix green, retro amber, and warm off-white,
  while retaining the unrestricted custom color picker.

## [0.3.2] - 2026-08-12

### Added

- A remembered save-dialog option to add a 12 px black border around
  screenshots and MP4 recordings.
- A permanent 12 px rounded bezel around the viewer's live monitor viewport.
- Viewer-side 100 ms source-signal loss detection with the same status card as
  the physical VGA output and automatic recovery when valid frames resume.
- A third screen-test cartridge view showing all 256 alphanumeric and graphics
  glyphs from the P2000M character ROM in a labelled 16 by 16 map.

### Fixed

- Replaced the Windows Qt IFW offline installer with an upgrade-aware NSIS
  package whose uninstaller remains usable and which accepts the existing
  installation directory when installing a newer release.

## [0.3.1] - 2026-08-08

### Added

- An optional viewer-side CRT phosphor afterglow effect with a persistent
  enable switch and a tunable 10–1000 ms brightness half-life.

### Fixed

- Corrected the Qt Installer Framework component identifier so the Windows
  installer can load its shortcut-creation script and proceed past Welcome.

### Changed

- Cached each platform's verified FFmpeg/x264 runtime in CI, while retaining
  source-archive checksum checks and a real MP4 encoding test on every run.

## [0.3.0] - 2026-08-08

### Added

- A synchronization watchdog that replaces a frozen source image with a
  dedicated `SIGNAL LOST` VGA screen when HSYNC/VSYNC-driven capture stops and
  restores live video after stable input timing returns; the screen identifies
  the adapter, compiled firmware version, and synchronization inputs awaited.
- A continuous, backpressure-safe binary USB screen mode which delivers
  complete CRC-checked,
  640 x 288 one-bit frames at up to half the P2000M source rate without taking
  ownership away from VGA scanout.
- A Qt 6 Windows viewer which discovers Pico CDC ports, verifies the VID2VGA
  firmware, enters screen mode automatically, reproduces VGA colors and
  geometry, and restores console mode when disconnected.
- Adapter configuration, connection, and About menus in the Windows viewer,
  including color pickers, border and scaling controls, phase trim, and
  optional persistent saving through the existing USB console.
- Smooth or sharp display filtering, pixel-perfect integer scaling, full-screen
  presentation, and lossless framebuffer screenshots in the Windows viewer.
- Lower-latency GUI processing to improve full-frame streaming throughput.
- Backward-compatible viewer negotiation for older per-frame-credit firmware.
- Independently recoverable PackBits screen records with automatic raw fallback,
  expanded-data CRC validation, codec round-trip tests, and live compression
  reporting in the viewer.
- An explicitly experimental 252 MHz, 1.30 V RP2350 configuration which retains
  exact 63 MHz capture and 25.2 MHz VGA clocks.
- Raw streaming as the viewer default, live raw/PackBits selection, aggregated
  PackBits USB writes, a faster table-driven framebuffer CRC, and end-to-end
  USB/render/paint/firmware timing telemetry.
- Visible viewer version information in the title, About dialog, Qt metadata,
  and Windows executable properties.
- A monitor-derived application icon for the Windows executable, taskbar,
  viewer window, and dialogs.
- A right-hand live performance panel with rolling history graphs for all
  transport, frame, rendering, firmware timing, and integrity metrics.
- FFmpeg-backed H.264 MP4 screen recording with bounded buffering, recording
  controls, progress reporting, and safe finalization on disconnect or exit.
- Mode-aware performance graphs which hide compression-only metrics in raw
  mode, plus rolling CRC errors per minute and a cumulative status-bar count.
- Native Linux and macOS USB CDC backends while preserving the established
  Windows SetupAPI and direct-COM implementation.
- Automated Windows ZIP, Linux AppImage, and Intel/Apple-silicon macOS DMG
  builds on every default-branch push and pull request.
- A graphical Windows offline installer with Start-menu and desktop shortcuts,
  license presentation, and an uninstall/maintenance tool; the portable ZIP
  remains available alongside it.
- A pinned, package-private FFmpeg 8.1.2 and x264 H.264 recording runtime in
  every desktop package, including verified corresponding source archives,
  license texts, checksums, build configuration, and an encoding smoke test.
- Exact-commit release promotion which refuses tags unless both firmware and
  every desktop package were already tested successfully on `master`.

### Changed

- Standardized source comments around Doxygen documentation blocks and concise
  implementation-rationale comments.
- Reserved the viewer status bar for the COM port, source frame number,
  cumulative CRC count, and operational recording messages instead of
  detailed performance statistics.
- Enabled Qt resource compilation so the application icon is available to
  windows and the taskbar, and displayed it prominently in the About dialog.
- Documented the cooling block used for sustained 252 MHz, 25 FPS operation and
  recommended equivalent RP2350 cooling for prolonged overclocked use.

## [0.2.0] - 2026-08-08

### Added

- A buildable P2000M screen-test cartridge with row and column rulers, a
  scrolling title, an elapsed-time display, a Space-selectable Matrix-style
  character-rain mode, and automatic cartridge-header signing and checksum
  generation.
- Four M3 mounting holes to the schematic and PCB design, together with updated
  board and schematic renders.
- Explicit per-file licensing, third-party notices, and SPDX metadata for the
  firmware, hardware, documentation, and bundled license texts.
- A `license` USB command and startup notice reporting the firmware's copyright,
  license, warranty, and source location.
- An independently colored border with selectable solid or dotted rendering,
  configurable and persistent through the USB console.

### Changed

- Tagged firmware releases now include the applicable license texts and
  third-party notices alongside the UF2 image.
- Expanded the documentation of the adapter hardware, P2000M source timing,
  signal conditioning, capture pipeline, pixel reconstruction, and VGA output.

### Fixed

- Corrected the DIN-5 connector mapping for the `VIDEO`, `HSYNC`, `VSYNC`, and
  ground signals in the schematic and PCB.
- Aligned capture to the trailing edge of `VSYNC` and skipped the two blank
  hardware rows, preventing a blank first character row from replacing the
  final visible row.

## [0.1.0] - 2026-08-07

### Added

- PIO and DMA capture of the active-low P2000M `VIDEO`, `HSYNC`, and `VSYNC`
  signals on Raspberry Pi Pico 2 GPIO16 through GPIO18.
- Software recovery of the source line and dot timing, with automatic sampling
  phase tuning, three-point pixel sampling, and a persistent manual phase trim.
- Tear-free 640 x 480 VGA output with the 640 x 288 source displayed in native
  one-to-one mode by default.
- Optional nearest-neighbour 5:3 vertical scaling to fill all 480 VGA lines.
- Triple buffering for both raw capture and decoded display frames, including
  asynchronous 50 Hz input to 60 Hz VGA frame repetition.
- Configurable foreground and background RGB colors, named color presets, and
  an optional foreground-colored screen-locking border.
- Interactive USB CDC console with input echo, line editing, quiet command
  mode, optional statistics logging, capture diagnostics, and firmware version
  reporting.
- Explicit flash persistence for colors, border, scaling mode, and manual
  sampling trim using redundant versioned records with CRC-32 validation.
- A single production firmware target and UF2 image named
  `p2000m-vid2vga-firmware`.
- GitHub Actions compilation checks and automatic tagged-release publishing of
  the Pico 2 UF2 binary.
- Automatic, version-pinned Pico SDK and `pico-extras` downloads during CMake
  configuration, with optional local-path overrides for offline builds.
- Pico 2/RP2350 project defaults and an early, actionable error when the Arm
  cross-compiler is not installed.

[0.4.0]: https://github.com/ifilot/p2000m-video-to-vga-adapter/compare/v0.3.2...v0.4.0
[0.3.2]: https://github.com/ifilot/p2000m-video-to-vga-adapter/compare/v0.3.1...v0.3.2
[0.3.1]: https://github.com/ifilot/p2000m-video-to-vga-adapter/compare/v0.3.0...v0.3.1
[0.3.0]: https://github.com/ifilot/p2000m-video-to-vga-adapter/compare/v0.2.0...v0.3.0
[0.2.0]: https://github.com/ifilot/p2000m-video-to-vga-adapter/compare/v0.1.0...v0.2.0
[0.1.0]: https://github.com/ifilot/p2000m-video-to-vga-adapter/releases/tag/v0.1.0

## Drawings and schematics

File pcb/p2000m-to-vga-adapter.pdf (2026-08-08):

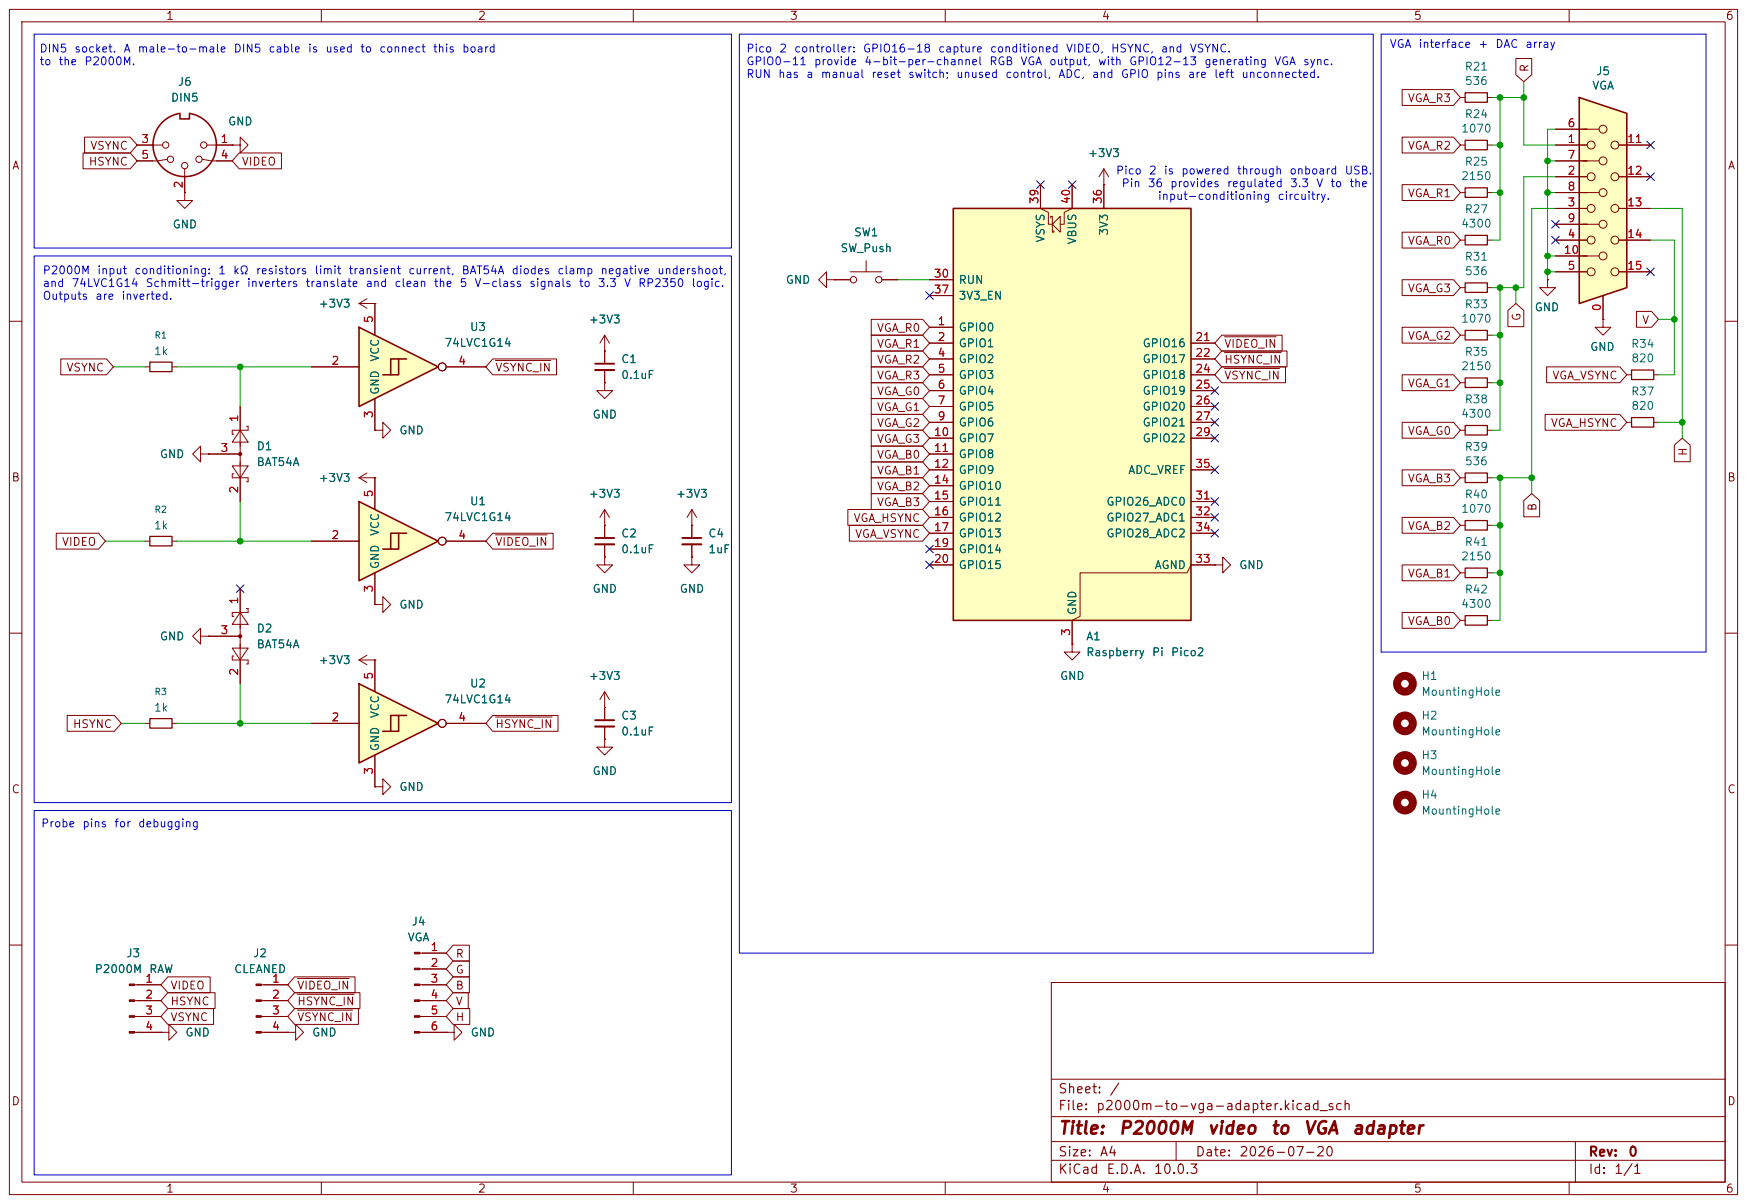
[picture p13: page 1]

VGA interface + DAC array Pico 2 controller: GPIO16-18 capture conditioned VIDEO, HSYNC, and VSYNC. GPIO0-11 provide 4-bit-per-channel RGB VGA output, with GPIO12-13 generating VGA sync. RUN has a manual reset switch; unused control, ADC, and GPIO pins are left unconnected. P2000M input conditioning: 1 kΩ resistors limit transient current, BAT54A diodes clamp negative undershoot, and 74LVC1G14 Schmitt-trigger inverters translate and clean the 5 V-class signals to 3.3 V RP2350 logic.
input-conditioning circuitry. DIN5 socket. A male-to-male DIN5 cable is used to connect this board

Sheet: /
File: p2000m-to-vga-adapter.kicad_sch
Title: P2000M video to VGA adapter

Size: A4 | Rev: 0
KiCad E.D.A. 10.0.3 | Id: 1/1

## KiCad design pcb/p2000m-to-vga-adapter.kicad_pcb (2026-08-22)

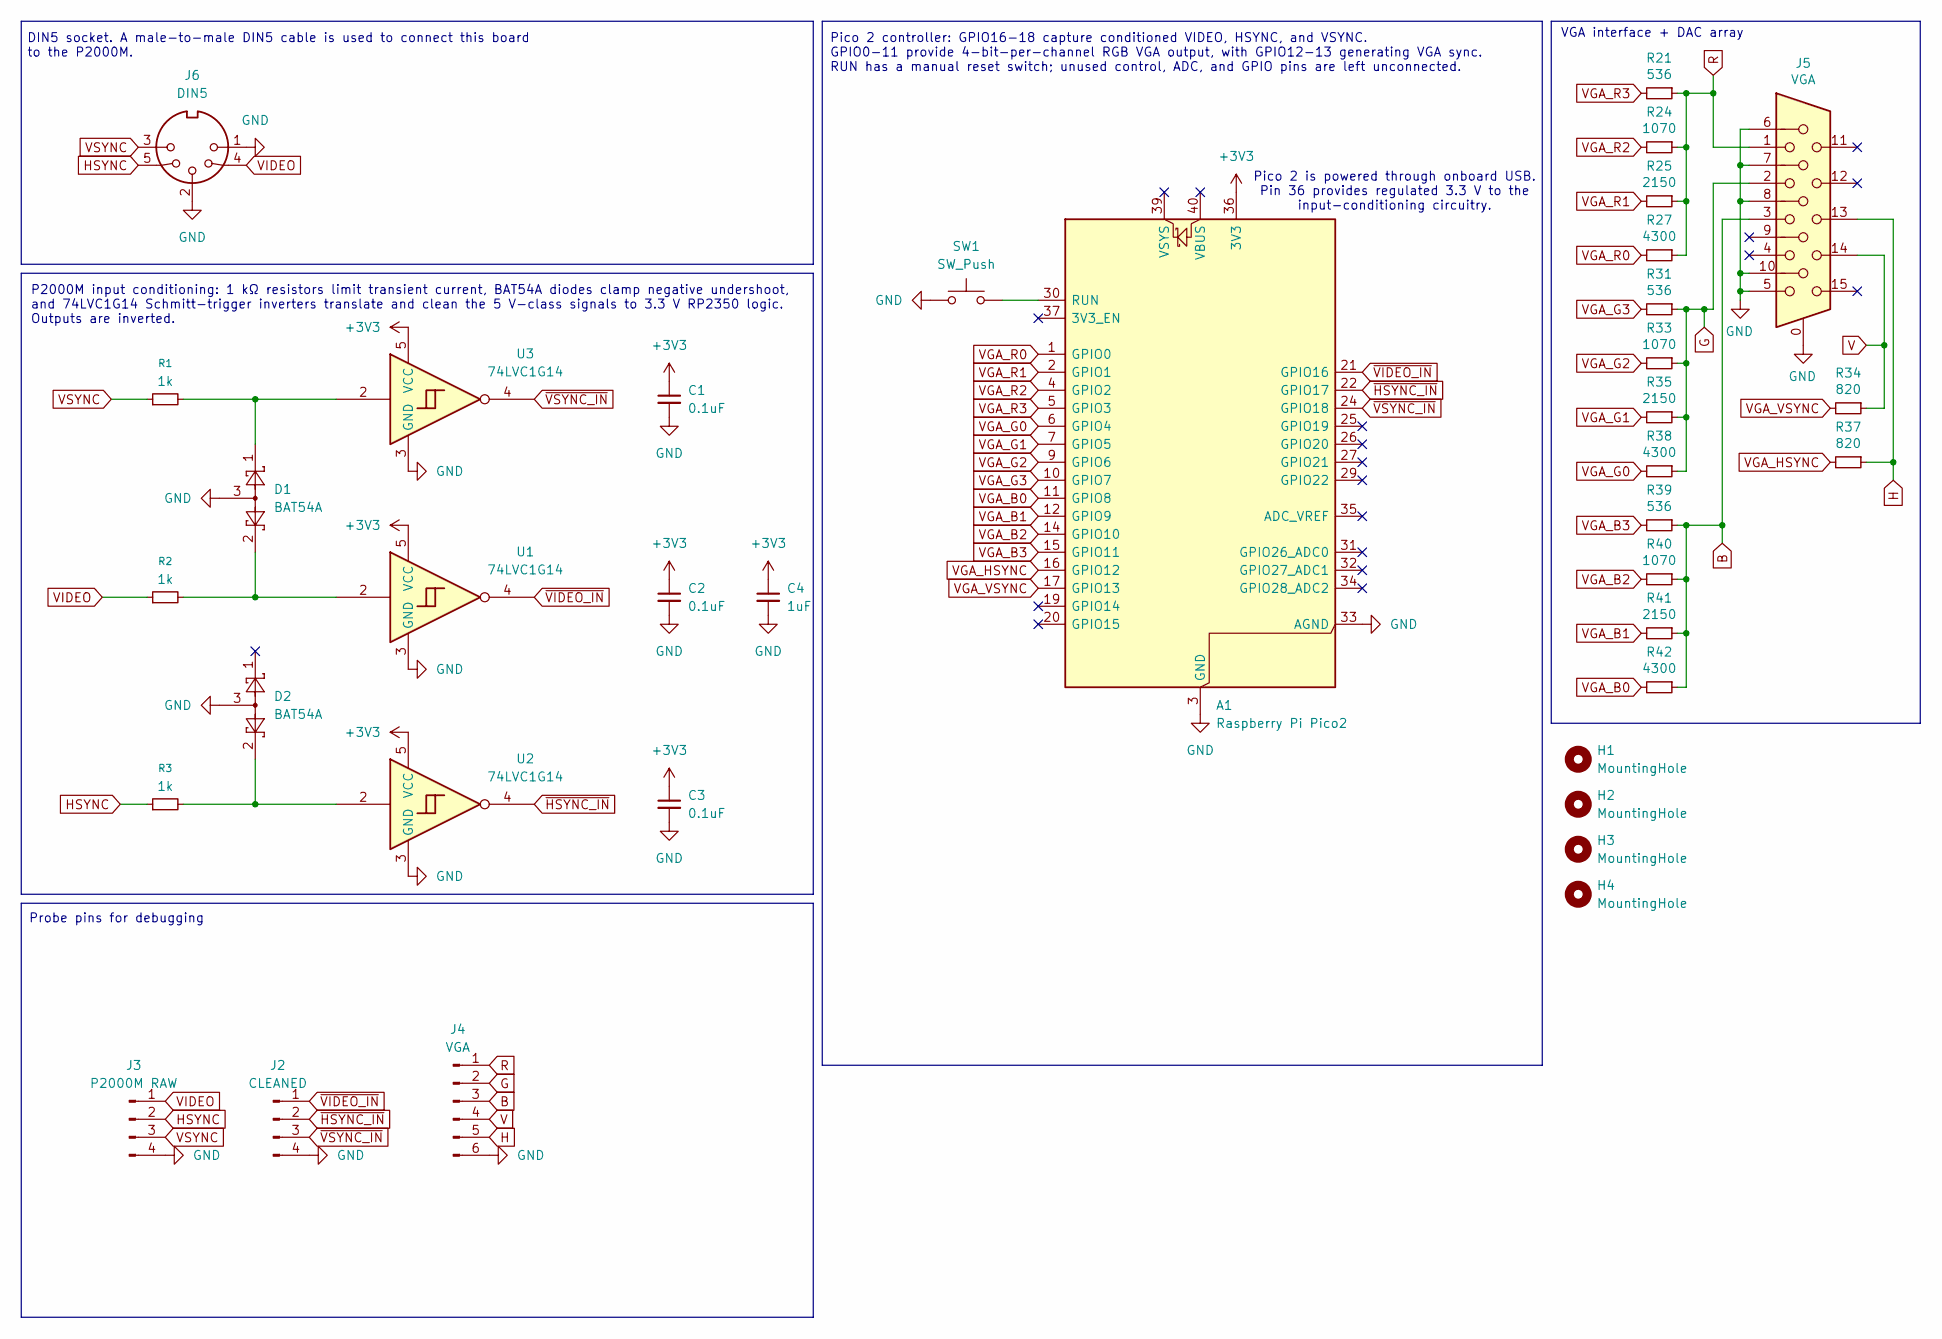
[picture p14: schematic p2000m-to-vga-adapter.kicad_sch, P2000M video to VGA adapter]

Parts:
A1: Raspberry Pi Pico2; RaspberryPi_Pico_Common_Unspecified
C1, C2, C3: 0.1uF; C_0805_2012Metric_Pad1.18x1.45mm_HandSolder; LCSC Part # C28233
C4: 1uF; C_0805_2012Metric_Pad1.18x1.45mm_HandSolder; LCSC Part # C28323
D1, D2: BAT54A; SOT-23; LCSC Part # C130910
H1, H2, H3, H4: MountingHole; MountingHole_3.2mm_M3_Pad_Via
J2: CLEANED; PinHeader_1x04_P2.54mm_Vertical
J3: P2000M RAW; PinHeader_1x04_P2.54mm_Vertical
J4: VGA; PinHeader_1x06_P2.54mm_Vertical
J5: VGA
J6: DIN5
R1, R2, R3: 1k; R_0805_2012Metric_Pad1.20x1.40mm_HandSolder; LCSC Part # C17513
R21, R31, R39: 536; R_0805_2012Metric_Pad1.20x1.40mm_HandSolder; LCSC Part # C343952
R24, R33, R40: 1070; R_0805_2012Metric_Pad1.20x1.40mm_HandSolder; LCSC Part # C865249
R25, R35, R41: 2150; R_0805_2012Metric_Pad1.20x1.40mm_HandSolder; LCSC Part # C515726
R27, R38, R42: 4300; R_0805_2012Metric_Pad1.20x1.40mm_HandSolder; LCSC Part # C473294
R34, R37: 820; R_0805_2012Metric_Pad1.20x1.40mm_HandSolder; LCSC Part # C865664
SW1: SW_Push; SW_PUSH_6mm
U1, U2, U3: 74LVC1G14; SOT-23-5_HandSoldering; LCSC Part # C131093

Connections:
+3V3: A1.36 (3V3), C1.1, C2.1, C3.1, C4.1, U1.5 (VCC), U2.5 (VCC), U3.5 (VCC)
B: J4.3, J5.3, R39.1, R40.1, R41.1, R42.1
G: J4.2, J5.2, R31.1, R33.1, R35.1, R38.1
GND: A1.3 (GND), A1.8 (GND), A1.13 (GND), A1.18 (GND), A1.23 (GND), A1.28 (GND), A1.33 (AGND), A1.38 (GND), C1.2, C2.2, C3.2, C4.2, D1.3, D2.3, J2.4, J3.4, J4.6, J5.0, J5.5, J5.6, J5.7, J5.8, J5.10, J6.1, J6.2, SW1.1, U1.3 (GND), U2.3 (GND), U3.3 (GND)
H: J4.5, J5.13, R37.1
HSYNC: J3.2, J6.5, R3.1
unnamed: A1.30 (RUN), SW1.2
unnamed: D1.1, R1.2, U3.2
unnamed: D1.2, R2.2, U1.2
unnamed: D2.2, R3.2, U2.2
R: J4.1, J5.1, R21.1, R24.1, R25.1, R27.1
V: J4.4, J5.14, R34.1
VGA_B0: A1.11 (GPIO8), R42.2
VGA_B1: A1.12 (GPIO9), R41.2
VGA_B2: A1.14 (GPIO10), R40.2
VGA_B3: A1.15 (GPIO11), R39.2
VGA_G0: A1.6 (GPIO4), R38.2
VGA_G1: A1.7 (GPIO5), R35.2
VGA_G2: A1.9 (GPIO6), R33.2
VGA_G3: A1.10 (GPIO7), R31.2
VGA_HSYNC: A1.16 (GPIO12), R37.2
VGA_R0: A1.1 (GPIO0), R27.2
VGA_R1: A1.2 (GPIO1), R25.2
VGA_R2: A1.4 (GPIO2), R24.2
VGA_R3: A1.5 (GPIO3), R21.2
VGA_VSYNC: A1.17 (GPIO13), R34.2
VIDEO: J3.1, J6.4, R2.1
VSYNC: J3.3, J6.3, R1.1
~HSYNC_IN: A1.22 (GPIO17), J2.2, U2.4
~VIDEO_IN: A1.21 (GPIO16), J2.1, U1.4
~VSYNC_IN: A1.24 (GPIO18), J2.3, U3.4

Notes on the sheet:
VGA interface + DAC array
DIN5 socket. A male-to-male DIN5 cable is used to connect this board to the P2000M.
P2000M input conditioning: 1 kΩ resistors limit transient current, BAT54A diodes clamp negative undershoot, and 74LVC1G14 Schmitt-trigger inverters translate and clean the 5 V-class signals to 3.3 V RP2350 logic. Outputs are inverted.
Pico 2 controller: GPIO16-18 capture conditioned VIDEO, HSYNC, and VSYNC. GPIO0-11 provide 4-bit-per-channel RGB VGA output, with GPIO12-13 generating VGA sync. RUN has a manual reset switch; unused control, ADC, and GPIO pins are left unconnected.
Pico 2 is powered through onboard USB. Pin 36 provides regulated 3.3 V to the input-conditioning circuitry.
Probe pins for debugging

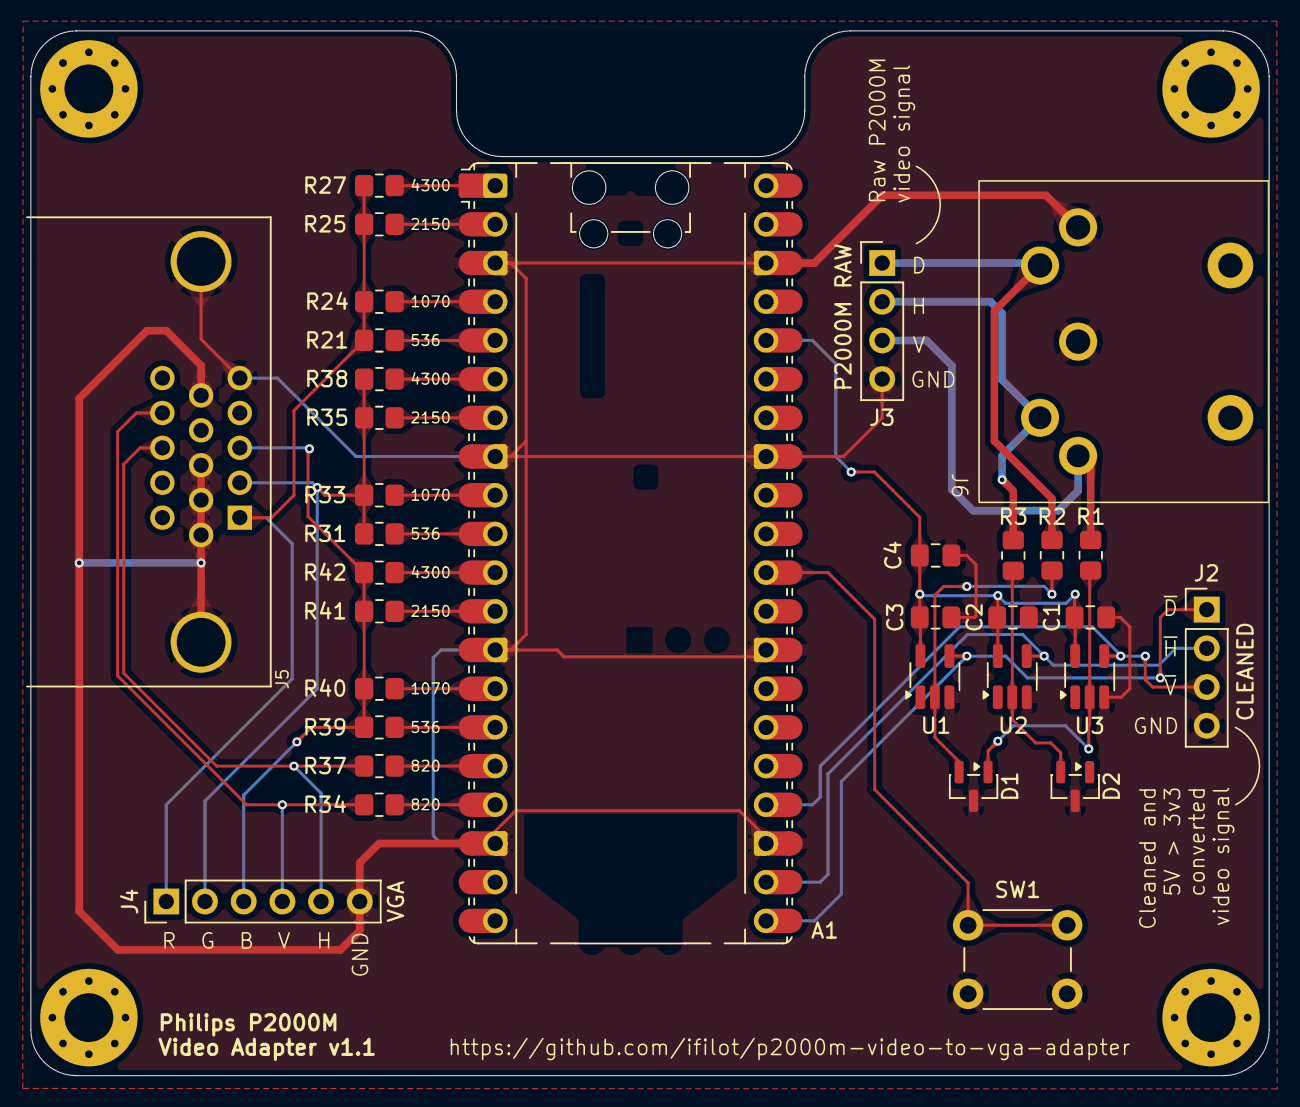
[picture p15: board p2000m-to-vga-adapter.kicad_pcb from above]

Board: 2 copper layers, 81.3 x 68.6 mm, 37 parts (0 on the bottom side), 31 nets.

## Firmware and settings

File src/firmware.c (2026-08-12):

/*
 * SPDX-FileCopyrightText: 2026 Ivo Filot <ivo@ivofilot.nl>
 * SPDX-License-Identifier: GPL-3.0-or-later
 */

/**
 * @file firmware.c
 * @brief Production P2000M capture, resampling, VGA, and USB-control firmware.
 */

#include <inttypes.h>
#include <stdbool.h>
#include <stddef.h>
#include <stdint.h>
#include <stdio.h>
#include <string.h>

#include "hardware/clocks.h"
#include "hardware/flash.h"
#include "hardware/sync.h"
#include "hardware/vreg.h"
#include "p2000m_capture.h"
#include "p2000m_packbits.h"
#include "p2000m_phosphor_noise.h"
#include "pico/flash.h"
#include "pico/multicore.h"
#include "pico/scanvideo.h"
#include "pico/scanvideo/composable_scanline.h"
#include "pico/stdio_usb.h"
#include "pico/stdlib.h"
#include "tusb.h"

/** Semantic firmware version supplied by the top-level CMake project. */
static const char firmware_version[] = "v" P2000M_VID2VGA_VERSION;
/** Product label shown on the VGA signal-loss status card. */
static const char signal_lost_product[] = "P2000M VID2VGA";
/** Primary message shown when source synchronization has timed out. */
static const char signal_lost_message[] = "SIGNAL LOST";
/** Compile-time firmware identification shown without requiring USB. */
static const char signal_lost_firmware[] =
    "FIRMWARE v" P2000M_VID2VGA_VERSION;
/** Synchronization inputs for which the capture engine is waiting. */
static const char signal_lost_waiting[] = "WAITING FOR HSYNC + VSYNC";

enum {
    /** Experimental 2x clock preserving exact capture and VGA divisors. */
    SYSTEM_CLOCK_KHZ = 252000,
    /** Maximum SDK-supported regulator setting used for the overclock. */
    SYSTEM_CORE_VOLTAGE_MV = 1300,
    /** Active VGA pixels per line. */
    VGA_WIDTH = 640,
    /** Active VGA lines per frame. */
    VGA_HEIGHT = 480,
    /** Background lines above the centered source image. */
    VGA_TOP_MARGIN = (VGA_HEIGHT - P2000M_CAPTURE_HEIGHT) / 2,
    /** Background lines below the centered source image. */
    VGA_BOTTOM_MARGIN = VGA_HEIGHT - VGA_TOP_MARGIN - P2000M_CAPTURE_HEIGHT,
    /** RAW_RUN header, 639 pixels, black reset pixel, and EOL tokens. */
    RAW_SCANLINE_TOKENS = (3 + VGA_WIDTH - 1) + 2 + 2,
    /** Maximum 32-bit scanvideo words required by a source line. */
    RAW_SCANLINE_WORDS = RAW_SCANLINE_TOKENS / 2,
    /** Packed one-bit words in a decoded source line. */
    DECODED_WORDS_PER_LINE = P2000M_CAPTURE_WIDTH / 32,
    /** Packed one-bit words in a decoded source frame. */
    DECODED_WORDS_PER_FRAME =
        DECODED_WORDS_PER_LINE * P2000M_CAPTURE_HEIGHT,
    /** Triple buffers decoupling core 0 decoding from VGA presentation. */
    DECODED_BUFFER_COUNT = 3,
    /** Lookup/style buffers used for atomic visual-setting changes. */
    DISPLAY_STYLE_COUNT = 2,
    /** Maximum USB command length including its null terminator. */
    COMMAND_BUFFER_SIZE = 64,
    /** Delay between statistics records while USB log streaming is active. */
    USB_LOG_INTERVAL_US = 2000000,
    /** Fixed binary header prepended to every streamed screen frame. */
    SCREEN_FRAME_HEADER_SIZE = 48,
    /** Packed bytes in one decoded 640 x 288 monochrome framebuffer. */
    SCREEN_FRAME_PAYLOAD_SIZE = DECODED_WORDS_PER_FRAME * sizeof(uint32_t),
    /** Maximum bytes offered to TinyUSB during one foreground-loop pass. */
    SCREEN_TX_SERVICE_BUDGET = 1024,
    /** PackBits bytes staged before each TinyUSB FIFO write. */
    SCREEN_PACKBITS_STAGING_SIZE = 1024,
    /** Source-frame sequence advance used to limit streaming to about 25 Hz. */
    SCREEN_SEQUENCE_STEP = 2,
    /** Number of alternating flash sectors used for atomic settings updates. */
    SETTINGS_SLOT_COUNT = 2,
    /** First settings sector; the RP2350's final flash sector stays reserved. */
    SETTINGS_FLASH_OFFSET =
        PICO_FLASH_SIZE_BYTES - (SETTINGS_SLOT_COUNT + 1) * FLASH_SECTOR_SIZE,
    /** File-format signature: ASCII "V2GA" when viewed little-endian. */
    SETTINGS_MAGIC = 0x41473256,
    /** On-flash settings structure version. */
    SETTINGS_VERSION = 3,
    /** Maximum time to coordinate each multicore flash lockout phase. */
    FLASH_LOCKOUT_TIMEOUT_MS = 1000,
    /** Core-start handshake value sent through the multicore FIFO. */
    VGA_READY_MAGIC = 0x56474131,
    /** Width of each letter in the built-in signal-loss font. */
    SIGNAL_LOST_GLYPH_WIDTH = 5,
    /** Height of each letter in the built-in signal-loss font. */
    SIGNAL_LOST_GLYPH_HEIGHT = 7,
    /** Integer enlargement applied to the signal-loss message. */
    SIGNAL_LOST_FONT_SCALE = 4,
    /** Integer enlargement applied to signal-loss status details. */
    SIGNAL_LOST_INFO_SCALE = 2,
    /** Uppercase letters and digits stored in the status-card font. */
    SIGNAL_LOST_FONT_GLYPHS = 36,
    /** Left edge of the centered signal-loss panel. */
    SIGNAL_LOST_PANEL_LEFT = 90,
    /** Right edge, exclusive, of the centered signal-loss panel. */
    SIGNAL_LOST_PANEL_RIGHT = 550,
    /** Top edge of the centered signal-loss panel. */
    SIGNAL_LOST_PANEL_TOP = 140,
    /** Bottom edge, exclusive, of the centered signal-loss panel. */
    SIGNAL_LOST_PANEL_BOTTOM = 340,
    /** Thickness of the red panel outline. */
    SIGNAL_LOST_PANEL_BORDER = 3,
    /** Top edge of the product-name line. */
    SIGNAL_LOST_PRODUCT_TOP = 164,
    /** Top edge of the primary warning line. */
    SIGNAL_LOST_MESSAGE_TOP = 200,
    /** Top edge of the firmware-version line. */
    SIGNAL_LOST_FIRMWARE_TOP = 254,
    /** Top edge of the synchronization-wait line. */
    SIGNAL_LOST_WAITING_TOP = 294,
};

_Static_assert((unsigned)VGA_WIDTH == (unsigned)P2000M_CAPTURE_WIDTH,
               "Step 3 requires one-to-one horizontal pixels");
_Static_assert(VGA_TOP_MARGIN == 96 && VGA_BOTTOM_MARGIN == 96,
               "The source image must be vertically centered");
_Static_assert((RAW_SCANLINE_TOKENS & 1u) == 0,
               "Composable scanline must occupy whole words");
_Static_assert(P2000M_CAPTURE_WIDTH % 32u == 0u,
               "Decoded scanlines must contain whole words");
_Static_assert(SETTINGS_FLASH_OFFSET % FLASH_SECTOR_SIZE == 0u,
               "Settings storage must start on a flash-sector boundary");

/** Standard 640 x 480, nominal 60 Hz VGA timing at a 25.2 MHz pixel clock. */
static const scanvideo_timing_t vga_timing_640x480_60 = {
    .clock_freq = 25200000,
    .h_active = VGA_WIDTH,
    .v_active = VGA_HEIGHT,
    .h_front_porch = 16,
    .h_pulse = 96,
    .h_total = 800,
    .h_sync_polarity = 1,
    .v_front_porch = 10,
    .v_pulse = 2,
    .v_total = 525,
    .v_sync_polarity = 1,
    .enable_clock = 0,
    .clock_polarity = 0,
    .enable_den = 0,
};

/** Scanvideo mode pairing the timing above with composable RGB444 output. */
static const scanvideo_mode_t firmware_vga_mode = {
    .default_timing = &vga_timing_640x480_60,
    .pio_program = &video_24mhz_composable,
    .width = VGA_WIDTH,
    .height = VGA_HEIGHT,
    .xscale = 1,
    .yscale = 1,
    .yscale_denominator = 1,
};

typedef enum {
    /** Buffer is available to the capture-to-monochrome decoder. */
    DECODED_FREE,
    /** Core 0 is currently writing the buffer. */
    DECODED_FILLING,
    /** Buffer contains a complete frame waiting for VGA presentation. */
    DECODED_READY,
    /** Core 1 is currently presenting the buffer. */
    DECODED_IN_USE,
} decoded_buffer_state_t;

/** Mutually exclusive interaction modes for the USB serial terminal. */
typedef enum {
    /** Editable, echoed command line with no unsolicited statistics. */
    USB_COMMAND_MODE,
    /** Periodic statistics stream; one exit key restores the prompt. */
    USB_LOG_MODE,
    /** Continuous binary 640 x 288 monochrome framebuffer stream. */
    USB_SCREEN_MODE,
} usb_interface_mode_t;

enum {
    /** Persisted VGA overlay enable bit. */
    DISPLAY_FLAG_BORDER_ENABLED = 1u << 0,
    /** Persisted VGA dotted-border selection bit. */
    DISPLAY_FLAG_BORDER_DOTTED = 1u << 1,
    /** Persisted full-height vertical-scaling selection bit. */
    DISPLAY_FLAG_VERTICAL_STRETCH = 1u << 2,
};

/** User-selectable colors and geometry overlay for one VGA frame. */
typedef struct {
    /** Foreground color as entered by the user, in 0xRRGGBB form. */
    uint32_t foreground_rgb;
    /** Background color as entered by the user, in 0xRRGGBB form. */
    uint32_t background_rgb;
    /** Border color as entered by the user, in 0xRRGGBB form. */
    uint32_t border_rgb;
    /** Whether to draw a one-pixel rectangle around the 640 x 288 image. */
    bool border_enabled;
    /** Whether the border alternates two colored and two clear pixels. */
    bool border_dotted;
    /** Whether to scale 288 source lines to all 480 active VGA lines. */
    bool vertical_stretch_enabled;
    /** Density of one-DAC-step phosphor-grain dimming on foreground pixels. */
    uint8_t phosphor_noise_level;
} display_style_t;

/** Versioned, checksummed display settings stored redundantly in flash. */
typedef struct {
    /** SETTINGS_MAGIC identifies records owned by this firmware. */
    uint32_t magic;
    /** SETTINGS_VERSION identifies the record layout. */
    uint16_t version;
    /** Exact structure size rejects incompatible future layouts. */
    uint16_t length;
    /** Monotonic counter used to select the newest of two valid slots. */
    uint32_t sequence;
    /** Saved foreground color in 0xRRGGBB form. */
    uint32_t foreground_rgb;
    /** Saved background color in 0xRRGGBB form. */
    uint32_t background_rgb;
    /** Saved border color in 0xRRGGBB form. */
    uint32_t border_rgb;
    /** Packed DISPLAY_FLAG_* values. */
    uint8_t display_flags;
    /** Saved p2000m_phosphor_noise_level_t value. */
    uint8_t phosphor_noise_level;
    /** Saved manual sampling-phase trim from -4 through +4 ticks. */
    int8_t manual_phase_ticks;
    /** Reserved for a future compatible settings addition. */
    uint8_t reserved;
    /** CRC-32 of every preceding byte in this structure. */
    uint32_t checksum;
} persisted_settings_t;

_Static_assert(sizeof(persisted_settings_t) == 32u,
               "Persisted settings format must remain exactly 32 bytes");
_Static_assert(offsetof(persisted_settings_t, checksum) == 28u,
               "Persisted settings checksum must remain at byte 28");

/** Version-two record retained solely to migrate existing saved settings. */
typedef struct {
    uint32_t magic;
    uint16_t version;
    uint16_t length;
    uint32_t sequence;
    uint32_t foreground_rgb;
    uint32_t background_rgb;
    uint32_t border_rgb;
    uint8_t border_enabled;
    uint8_t border_dotted;
    uint8_t vertical_stretch_enabled;
    int8_t manual_phase_ticks;
    uint32_t checksum;
} persisted_settings_v2_t;

_Static_assert(sizeof(persisted_settings_v2_t) == 32u,
               "Version-two settings format must remain exactly 32 bytes");
_Static_assert(offsetof(persisted_settings_v2_t, checksum) == 28u,
               "Version-two settings checksum must remain at byte 28");

/** Version-one record retained solely to migrate existing saved settings. */
typedef struct {
    uint32_t magic;
    uint16_t version;
    uint16_t length;
    uint32_t sequence;
    uint32_t foreground_rgb;
    uint32_t background_rgb;
    uint8_t border_enabled;
    uint8_t vertical_stretch_enabled;
    int8_t manual_phase_ticks;
    uint8_t reserved[5];
    uint32_t checksum;
} persisted_settings_v1_t;

_Static_assert(sizeof(persisted_settings_v1_t) == 32u,
               "Legacy settings format must remain exactly 32 bytes");
_Static_assert(offsetof(persisted_settings_v1_t, checksum) == 28u,
               "Legacy settings checksum must remain at byte 28");

/** RAM-resident parameters consumed by the safe flash callback. */
typedef struct {
    /** Sector-aligned flash offset to erase. */
    uint32_t offset;
    /** Sector-multiple byte count to erase. */
    size_t erase_size;
    /** Whether to program page after erasing. */
    bool program_page;
    /** Full flash page containing the settings record and erased padding. */
    uint8_t page[FLASH_PAGE_SIZE];
} flash_mutation_t;

/** Named RGB color accepted by the USB command interface. */
typedef struct {
    /** Case-insensitive name typed by the user. */
    const char *name;
    /** Eight-bit-per-channel color in 0xRRGGBB form. */
    uint32_t rgb;
} color_preset_t;

/** Presets shared by the foreground and background commands. */
static const color_preset_t color_presets[] = {
    {.name = "black",   .rgb = 0x000000u},
    {.name = "white",   .rgb = 0xffffffu},
    {.name = "green",   .rgb = 0x00ff00u},
    {.name = "amber",   .rgb = 0xffb000u},
    {.name = "cyan",    .rgb = 0x00ffffu},
    {.name = "magenta", .rgb = 0xff00ffu},
    {.name = "red",     .rgb = 0xff0000u},
    {.name = "blue",    .rgb = 0x0000ffu},
    {.name = "yellow",  .rgb = 0xffff00u},
    {.name = "gray",    .rgb = 0x808080u},
};

/** Three decoded frames shared between the capture and VGA cores. */
static uint32_t decoded_frames[DECODED_BUFFER_COUNT][DECODED_WORDS_PER_FRAME];
/** Ownership state for each entry in decoded_frames. */
static decoded_buffer_state_t decoded_states[DECODED_BUFFER_COUNT];
/** P2000M capture sequence number represented by each decoded frame. */
static uint32_t decoded_sequences[DECODED_BUFFER_COUNT];
/** Cross-core lock protecting decoded_states and decoded_sequences. */
static spin_lock_t *decoded_lock;
/** Whether the USB transmitter currently holds each decoded buffer immutable. */
static bool decoded_usb_holds[DECODED_BUFFER_COUNT];

/** Double-buffered byte-to-eight-pixel lookup tables for arbitrary colors. */
static uint16_t monochrome_pixels[DISPLAY_STYLE_COUNT][256][8];
/** Double-buffered user display settings corresponding to the lookup tables. */
static display_style_t display_styles[DISPLAY_STYLE_COUNT];
/** Style most recently published by core 0 for the next VGA frame. */
static volatile unsigned requested_style_index;
/** Style accepted by core 1 at a VGA frame boundary. */
static volatile unsigned applied_style_index;
/** Style used by core 1 throughout the current VGA frame. */
static unsigned displayed_style_index;

/** Decoded buffer currently being presented, or -1 before the first frame. */
static int displayed_buffer = -1;
/** Source capture sequence currently being presented. */
static uint32_t displayed_sequence;
/** Input-lock state sampled by core 1 at the current VGA frame boundary. */
static bool displayed_signal_present;

/** Lifetime VGA frame counter, written by core 1. */
static volatile uint32_t generated_vga_frames;
/** Number of VGA frame boundaries that selected a new decoded source frame. */
static volatile uint32_t source_frame_swaps;
/** Number of VGA frames that deliberately repeated the preceding source. */
static volatile uint32_t repeated_vga_frames;
/** Number of VGA frames generated before the first decoded source existed. */
static volatile uint32_t blank_vga_frames;
/** Number of complete raw frames converted into decoded monochrome frames. */
static volatile uint32_t decoded_source_frames;
/** Duration in microseconds of the most recent full-frame decode. */
static volatile uint32_t last_decode_us;
/** Longest full-frame decode observed since boot, in microseconds. */
static volatile uint32_t maximum_decode_us;
/** Partially received newline-terminated command from the USB CDC port. */
static char usb_command_buffer[COMMAND_BUFFER_SIZE];
/** Number of valid characters currently held in usb_command_buffer. */
static size_t usb_command_length;
/** True while discarding an overlong command up to its terminating newline. */
static bool usb_command_overflow;
/** Current interactive or streaming behavior of the USB terminal. */
static usb_interface_mode_t usb_interface_mode = USB_COMMAND_MODE;
/** Suppresses LF when a terminal sends CR/LF as one line terminator. */
static bool usb_ignore_next_lf;
/** Timestamp for the next periodic record in USB_LOG_MODE. */
static uint64_t next_usb_log_us;
/** One complete screen-frame header assembled without structure padding. */
static uint8_t screen_frame_header[SCREEN_FRAME_HEADER_SIZE];
/** Decoded buffer currently being transmitted, or -1 while idle. */
static int screen_tx_buffer = -1;
/** Next unsent byte within screen_frame_header. */
static size_t screen_tx_header_offset;
/** Next unsent byte within the packed decoded framebuffer. */
static size_t screen_tx_payload_offset;
/** Sequence represented by screen_tx_buffer. */
static uint32_t screen_tx_sequence;
/** Most recently completed USB frame sequence. */
static uint32_t screen_last_sequence;
/** Whether screen_last_sequence contains a completed frame. */
static bool screen_last_sequence_valid;
/** Whether the current screen session may send PackBits records. */
static bool screen_packbits_enabled;
/** Whether the frame in screen_tx_buffer selected PackBits encoding. */
static bool screen_tx_packbits;
/** Bytes in the encoded or raw payload currently being transmitted. */
static size_t screen_tx_payload_size;
/** Raw input position used by the streaming PackBits encoder. */
static size_t screen_tx_packbits_input_offset;
/** Aggregated PackBits runs submitted to TinyUSB in large writes. */
static uint8_t screen_tx_packbits_staging[SCREEN_PACKBITS_STAGING_SIZE];
/** Valid bytes in screen_tx_packbits_staging. */
static size_t screen_tx_packbits_staging_size;
/** Next unsent byte in screen_tx_packbits_staging. */
static size_t screen_tx_packbits_staging_offset;
/** CPU microseconds spent encoding the active frame into staging blocks. */
static uint32_t screen_tx_encode_us;
/** Timestamp at which the active record was prepared for transmission. */
static uint64_t screen_tx_started_us;
/** Complete screen frames queued to TinyUSB since boot. */
static uint32_t screen_frames_sent;
/** Raw fallback records queued since boot. */
static uint32_t screen_raw_frames_sent;
/** PackBits records queued since boot. */
static uint32_t screen_packbits_frames_sent;
/** Header and payload bytes queued since boot. */
static uint64_t screen_bytes_sent;
/** Payload bytes in the most recently completed record. */
static uint32_t screen_last_payload_size;
/** Most recent and maximum preparation durations. */
static uint32_t screen_last_prepare_us;
static uint32_t screen_maximum_prepare_us;
/** Most recent and maximum streaming-encoder CPU durations. */
static uint32_t screen_last_encode_us;
static uint32_t screen_maximum_encode_us;
/** Most recent and maximum end-to-end record queue durations. */
static uint32_t screen_last_tx_us;
static uint32_t screen_maximum_tx_us;
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
int main(void) {
    // EXPERIMENTAL: 252 MHz is well beyond the RP2350's 150 MHz rating. Raise
    // the regulator first and allow it to settle. This deliberately stays at
    // the SDK's 1.30 V limit rather than disabling the voltage safety limit.
    vreg_set_voltage(VREG_VOLTAGE_1_30);
    sleep_us(1000u);
    if (!set_sys_clock_khz(SYSTEM_CLOCK_KHZ, true)) {
        panic("Unable to set the experimental 252 MHz system clock");
    }

    // The application initializes TinyUSB while stdio_usb retains the default
    // CDC descriptors and installs its low-priority endpoint-service worker.
    tusb_init();
    stdio_init_all();
    validate_settings_flash_region();
    display_style_t initial_style = default_display_style();
    restored_saved_settings = load_saved_configuration(&initial_style);
    configuration_dirty = false;
    initialize_display_styles(&initial_style);

    // scanvideo has fixed ownership of DMA channel 0, so configure it before
    // capture dynamically claims two other channels.
    if (!scanvideo_setup(&firmware_vga_mode)) {
        panic("Unable to initialize VGA scanvideo");
    }
    initialize_decoded_buffers();

    // Capture owns dynamically allocated DMA channels, so it must start after
    // scanvideo has claimed channel 0 but before core 1 can request a frame.
    p2000m_capture_start();
    if (!p2000m_capture_set_sample_phase(saved_manual_phase_ticks)) {
        panic("Saved manual phase trim is invalid");
    }
    multicore_launch_core1(vga_core_main);
    if (multicore_fifo_pop_blocking() != VGA_READY_MAGIC) {
        panic("Unable to start VGA rendering core");
    }
    scanvideo_timing_enable(true);

    bool announced = false;
    uint64_t next_automatic_tune = time_us_64() + 250000u;
    while (true) {
        const uint64_t now = time_us_64();
        if (now >= next_automatic_tune) {
            const bool tuned = p2000m_capture_autotune(NULL);
            next_automatic_tune = now + (tuned ? 5000000u : 100000u);
        }
        (void)decode_latest_source_frame();

        if (!stdio_usb_connected()) {
            announced = false;
            abort_screen_transfer();
            usb_interface_mode = USB_COMMAND_MODE;
            usb_command_length = 0u;
            usb_command_overflow = false;
            usb_ignore_next_lf = false;
            // Keep converting at the input frame rate even without a USB host.
            // Triple buffering ensures VGA always retains a complete READY
            // frame while core 0 prepares the next one.
            sleep_ms(1);
            continue;
        }

        if (!announced) {
            sleep_ms(100);
            printf("P2000M VID2VGA firmware %s ready: 640x288 source to "
                   "640x480 VGA.\n", firmware_version);
            print_firmware_license();
            print_display_settings();
            printf("Enter HELP for available commands.\n");
            announced = true;
            print_usb_prompt();
        }

        poll_usb_commands();

        const uint64_t status_now = time_us_64();
        if (usb_interface_mode == USB_SCREEN_MODE) {
            service_screen_output();
        } else if (usb_interface_mode == USB_LOG_MODE &&
            status_now >= next_usb_log_us) {
            print_statistics();
            next_usb_log_us = status_now + USB_LOG_INTERVAL_US;
        }
        sleep_ms(1);
    }
}

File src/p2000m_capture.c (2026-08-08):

/*
 * SPDX-FileCopyrightText: 2026 Ivo Filot <ivo@ivofilot.nl>
 * SPDX-License-Identifier: GPL-3.0-or-later
 */

/**
 * @file p2000m_capture.c
 * @brief PIO/DMA acquisition and line-locked software resampling for P2000M.
 */

#include "p2000m_capture.h"

#include <stdint.h>

#include "hardware/dma.h"
#include "hardware/irq.h"
#include "hardware/pio.h"
#include "hardware/sync.h"
#include "p2000m_capture.pio.h"
#include "pico/binary_info.h"
#include "pico/stdlib.h"

enum {
    /** Experimental clock retaining exact 63 MHz capture and 25.2 MHz VGA. */
    REQUIRED_SYSTEM_CLOCK_HZ = 252000000,
    /** Integer PIO divisor retaining the original 63 MHz sampling clock. */
    CAPTURE_CLOCK_DIVIDER = 4,

    /** Conditioned, active-low monochrome video input. */
    VIDEO_PIN = 16,
    /** Conditioned, active-low horizontal synchronization input. */
    HSYNC_PIN = 17,
    /** Conditioned, active-low vertical synchronization input. */
    VSYNC_PIN = 18,

    /** Raw buffers used to decouple DMA capture from software consumers. */
    CAPTURE_BUFFER_COUNT = 3,
    /** Initial frame-line count plus one sample-group count per visible line. */
    TX_COMMAND_COUNT = 1 + P2000M_CAPTURE_HEIGHT,
    /** PIO y-loop initializer for 288 lines. */
    FRAME_LINE_COUNT = P2000M_CAPTURE_HEIGHT - 1,
    /** Fourteen-sample PIO groups captured from each visible source line. */
    LINE_SAMPLE_GROUP_COUNT = 228,
    /** PIO x-loop initializer for 228 groups. */
    LINE_SAMPLE_GROUP_COUNT_MINUS_ONE = LINE_SAMPLE_GROUP_COUNT - 1,

    /** Earliest supported user trim in capture ticks. */
    MANUAL_PHASE_MIN = -4,
    /** Latest supported user trim in capture ticks. */
    MANUAL_PHASE_MAX = 4,
    /** First of the five automatic phase candidates. */
    TUNING_FIRST_PHASE_TICK = 12,
    /** Safe phase used before the first content-based tune. */
    TUNING_INITIAL_PHASE_TICK = 14,
    /** Nominal 64 microsecond line at the 63 MHz capture clock. */
    NOMINAL_LINE_TICKS = 4032,
    /** Earliest credible P2000M VSYNC-to-VSYNC period. */
    MINIMUM_FRAME_PERIOD_US = 19000,
    /** Latest credible P2000M VSYNC-to-VSYNC period. */
    MAXIMUM_FRAME_PERIOD_US = 21000,
    /** Missing-frame interval after which the input is considered lost. */
    SIGNAL_LOSS_TIMEOUT_US = 100000,
    /** Complete P2000M horizontal period expressed in source dot periods. */
    SOURCE_DOTS_PER_LINE = 768,
    /** Early and late samples taken around every mapped pixel center. */
    TUNING_WINDOW_RADIUS_TICKS = 1,
};

/** Ownership states for one entry in the triple raw-frame buffer. */
typedef enum {
    /** Available as the next DMA destination. */
    BUFFER_FREE,
    /** Currently being written by capture DMA. */
    BUFFER_FILLING,
    /** Complete and available for a consumer. */
    BUFFER_READY,
    /** Held immutable by one software consumer. */
    BUFFER_IN_USE,
} buffer_state_t;

_Static_assert(P2000M_CAPTURE_SAMPLES_PER_WORD == 28,
               "PIO packing assumes 28 useful samples per word");
_Static_assert(P2000M_CAPTURE_TICKS_PER_WORD == 30,
               "PIO timing assumes two branch cycles per packed word");
_Static_assert(P2000M_CAPTURE_WORDS_PER_LINE * 2 == LINE_SAMPLE_GROUP_COUNT,
               "Each FIFO word must contain two sample groups");
_Static_assert(REQUIRED_SYSTEM_CLOCK_HZ / CAPTURE_CLOCK_DIVIDER ==
                   P2000M_CAPTURE_SAMPLE_CLOCK_HZ,
               "Capture PIO must retain the exact 63 MHz clock");

/** PIO block reserved for input capture; scanvideo uses PIO0. */
static PIO capture_pio = pio1;
/** Claimed state-machine number within capture_pio. */
static unsigned capture_sm;
/** Instruction-memory offset of p2000m_capture_program. */
static unsigned capture_program_offset;
/** DMA channel moving PIO RX FIFO data into capture buffers. */
static int capture_rx_dma;
/** DMA channel feeding per-line loop counts to the PIO TX FIFO. */
static int capture_tx_dma;
/** Lock protecting raw-buffer ownership and capture statistics. */
static spin_lock_t *buffer_lock;

/** Triple-buffered packed oversampling data. */
static uint32_t capture_buffers[CAPTURE_BUFFER_COUNT][P2000M_CAPTURE_WORDS_PER_FRAME];
/** DMA-fed PIO loop counts: frame line count followed by line group counts. */
static uint32_t tx_commands[TX_COMMAND_COUNT];
/** Double-buffered horizontal maps, atomically exchanged after rebuilding. */
static p2000m_capture_pixel_map_t
    pixel_maps[2][P2000M_CAPTURE_WIDTH];

/** Ownership state corresponding to each capture_buffers entry. */
static buffer_state_t buffer_states[CAPTURE_BUFFER_COUNT];
/** Monotonic frame sequence corresponding to each capture buffer. */
static uint32_t buffer_sequences[CAPTURE_BUFFER_COUNT];
/** Buffer currently receiving capture DMA data. */
static unsigned capture_fill_index;
/** Number of completed raw frames since boot. */
static uint32_t captured_frames;
/** Number of unread ready frames replaced by newer capture data. */
static uint32_t stale_frames_replaced;
/** Latest measured frame period in microseconds. */
static uint32_t last_frame_period_us;
/** Completion timestamp used to derive last_frame_period_us. */
static uint64_t last_frame_time_us;
/** Low-pass-filtered frame period in 24.8 fixed-point microseconds. */
static uint32_t filtered_frame_period_us_q8;
/** Recovered line period in 16.16 fixed-point capture ticks. */
static uint32_t recovered_line_ticks_q16 = NOMINAL_LINE_TICKS << 16;
/** Number of successful content-based phase tuning passes. */
static uint32_t autotune_runs;
/** White-sample score at the currently selected phase. */
static uint32_t autotune_score;
/** Duration of the latest tuning pass in microseconds. */
static uint32_t last_autotune_us;
/** Longest tuning pass observed since boot in microseconds. */
static uint32_t maximum_autotune_us;
/** Phase selected automatically, in 63 MHz capture ticks. */
static int32_t auto_phase_ticks = TUNING_INITIAL_PHASE_TICK;
/** User-controlled trim added to auto_phase_ticks. */
static int32_t manual_phase_ticks;
/** Index of the pixel map visible to consumers. */
static unsigned active_pixel_map;

/**
 * @brief Evaluate sync lock from one consistent capture-timing snapshot.
 *
 * @param now Current monotonic time in microseconds.
 * @param last_frame_time Completion time of the latest captured frame.
 * @param frame_period Latest measured frame period in microseconds.
 * @return true when recent complete frames have credible source timing.
 */
static bool capture_timing_is_locked(uint64_t now,
                                     uint64_t last_frame_time,
                                     uint32_t frame_period) {
    return last_frame_time != 0u &&
        frame_period >= MINIMUM_FRAME_PERIOD_US &&
        frame_period <= MAXIMUM_FRAME_PERIOD_US &&
        now - last_frame_time <= SIGNAL_LOSS_TIMEOUT_US;
}
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

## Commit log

2026-07-20 Finalizing design
    [p2000m-to-vga-adapter.kicad_pcb, p2000m-to-vga-adapter.kicad_sch]
2026-07-24 Fixing DIN5 footprint
    [p2000m-to-vga-adapter.kicad_pcb]
2026-08-08 Patch v0.2.0 (#2)
    * Fixing DIN5 connector
    * Adding licenses, adding test program and updating README.md
    * Polishing screentest program
    * Expanding screentest, adding cartridge signing, fixing bug in firwmware
    * Adding hero image and bumping version to 0.2.0
    * Downsampling hero image
    * Add feature to configure border style and color
    [p2000m-to-vga-adapter.kicad_pcb, p2000m-to-vga-adapter.kicad_sch]
2026-08-08 Patch v0.3.0 (#3)
    * Initial commit GUI
    * Polishing live recording app
    * Creating packaging
    * Fixing packaging
    [firmware.c, main.cpp, p2000m_capture.c]
2026-08-12 Adding phosphor noise and adding preset colors to configuration panel
    [firmware.c, main.cpp]
2026-08-22 Adding enclosure and expanding README.md
    [bottom.stl, p2000m-to-vga-adapter.kicad_pcb, p2000m-vga-v1.step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]
